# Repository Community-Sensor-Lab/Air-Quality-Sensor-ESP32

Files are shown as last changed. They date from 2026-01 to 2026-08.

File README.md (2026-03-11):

<div align="center">

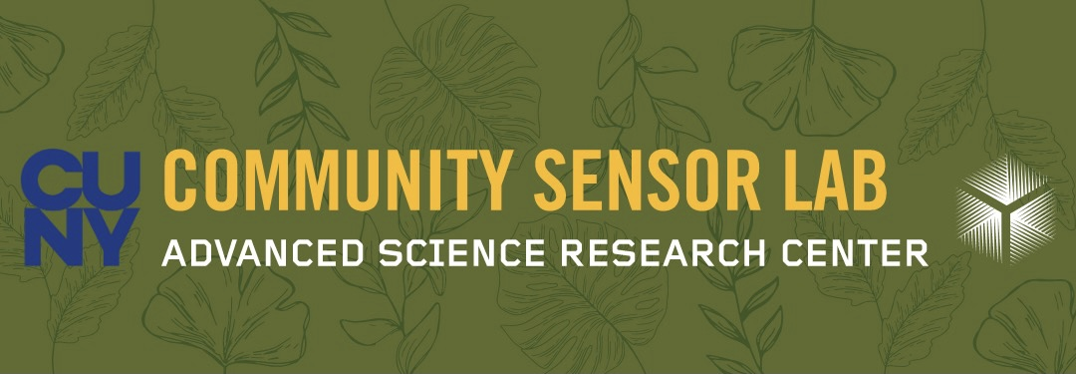
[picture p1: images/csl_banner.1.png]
Banner


</div>

#  Air Quality Sensor Assembly Guide (ESP32 version)

<div align="center">









*Build your own portable environmental monitoring station*

</div>

---

##  What You'll Build

<p align="center">
  
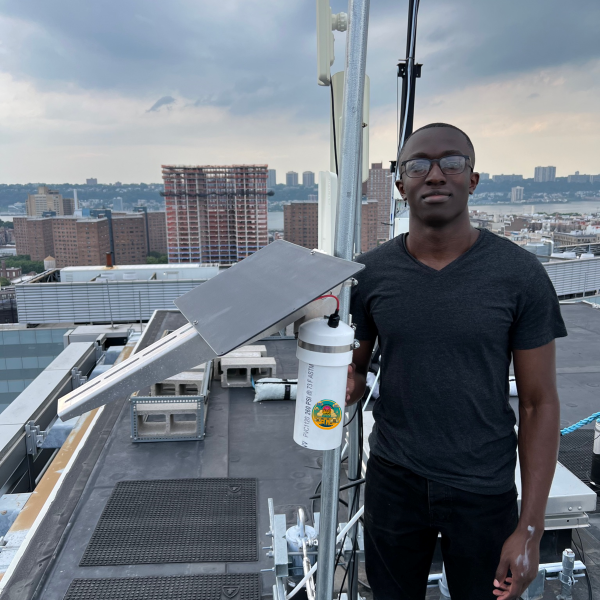
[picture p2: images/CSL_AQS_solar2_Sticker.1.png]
  
</p>

> **A complete air quality monitoring system** that measures Temperature, Relative Humidity, CO<sub>2</sub>, Volatiles (VOCs), Nitrogen Oxides (NOx), and particulate matter PM.

###  Key Features
-  **Multi-sensor monitoring** 5 environmental parameters
-  **SD card data logging** for long data records  
-  **Mini OLED screen** for real-time data display
-  **WiFi connectivity** integrated to Google Sheets
-  **Semi Portable design** for indoor/outdoor use

###  Learning Outcomes
By completing this project, you'll gain hands-on experience with:
-  **Electronics assembly** and soldering techniques
-  **Arduino programming** and sensor integration
-  **Data visualization** and analysis methods
-  **IoT connectivity** and cloud services

---

##  Project Overview

| **Duration** | **Difficulty** | **Prerequisites** |
|:---:|:---:|:---:|
| 6-8 hours | Beginner | Basic computer skills |

*Multiple sessions recommended for best learning experience*

---

##  Complete Guide Contents

| Section | Title | Author | Description |
|:---:|---|---|---|
| **0** | [ Parts List](Contents/Parts-List.md) | *Mark* | Complete components inventory |
| **1** | [ Skills & Tools](Contents/1.%20Required-Skills-and-Tools.md) | *Lorena* | What you'll need to get started |
| **2** | [ Arduino Setup](Contents/2.%20Installing-Arduino-and-Getting-Started-2.3.6.md) | *Vincent* | Software installation & basics |
| **3** | [ Soldering Guide](Contents/3.%20Soldering-Pins-and-Headers-on-Boards.md) | | Hardware assembly techniques |
| **3.5** | [ WiFi Configuration](Contents/3.5%20Feather-M0-WiFi-Setup-Procedure.md) | | Network connectivity setup |
| **4** | [ Component Assembly](Contents/4%20Breadboard-Assembly-and-Component-Code-Testing.md) | *Lorena* | Breadboard wiring & testing |
| **5** | [ Code Workshop](Contents/5.%20Code-Activity.md) | *Lorena* | Programming fundamentals |
| **6** | [ GitHub Integration](Contents/6.%20Downloading-CSL-AQS-Code-from-GitHub.md) | *Mark* | Source code management |
| **7** | [ Google Sheets Logging](Contents/7.%20Posting-to-Google-Logging-Spreadsheet.md) | *Vincent* | Cloud data integration |
| **8** | [ Data Visualization](Contents/8.%20How-to-Make-Data-Graphs-Lines-and-Time-Series.md) | *Ricardo* | Creating meaningful charts |
| **9** | [ PCB Design](Contents/9.%20Design-and-Assembly-of-PCB.md) | *Mark* | Professional circuit boards |
| **9.8** | [ Assembly of AQS Monitor on PCB Board](Contents/9.8%20Assembley-of-AQS-Monitor-on-PCB-Board.md) | | Soldering and mounting components onto the PCB |
| **10** | [ Final Assembly](Contents/10.%20AQS-PCB-Mount.md) | *Vincent* | Enclosure & mounting |

---

##  Quick Start

1. **Gather Materials** → Check the [Parts List](Contents/Parts-List.md)
2. **Setup Workspace** → Review [Skills & Tools](Contents/1.%20Required-Skills-and-Tools.md)
3. **Install Software** → Follow [Arduino Setup](Contents/2.%20Installing-Arduino-and-Getting-Started-2.3.6.md)
4. **Start Building!** → Begin with component assembly

---

##  Documentation Levels

| Guide Type | Best For | Link |
|---|---|---|
| **Quick Reference** | Experienced builders | *This README* |
| **Detailed Walkthrough** | First-time builders | [Comprehensive Guide](README-DETAILED.md) |

---

##  Perfect For

-  **STEM Education Programs**
-  **Students learning electronics**
-  **DIY environmental monitoring**
-  **Citizen science projects**

---

##  Contributing

Found an issue or have suggestions? We welcome contributions to improve this educational resource!

---

<div align="center">

**Transform your understanding of environmental monitoring while building something truly useful**





</div>

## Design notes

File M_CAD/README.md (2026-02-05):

<div align="center">

# Air Quality Sensor CAD

<div align="center">

### Most up-to-date CAD files for the Air Quality Sensor, including all mounts, stands and soldering tools.
---
<div align="center">

Complete Assembly of AQS with all Sensors
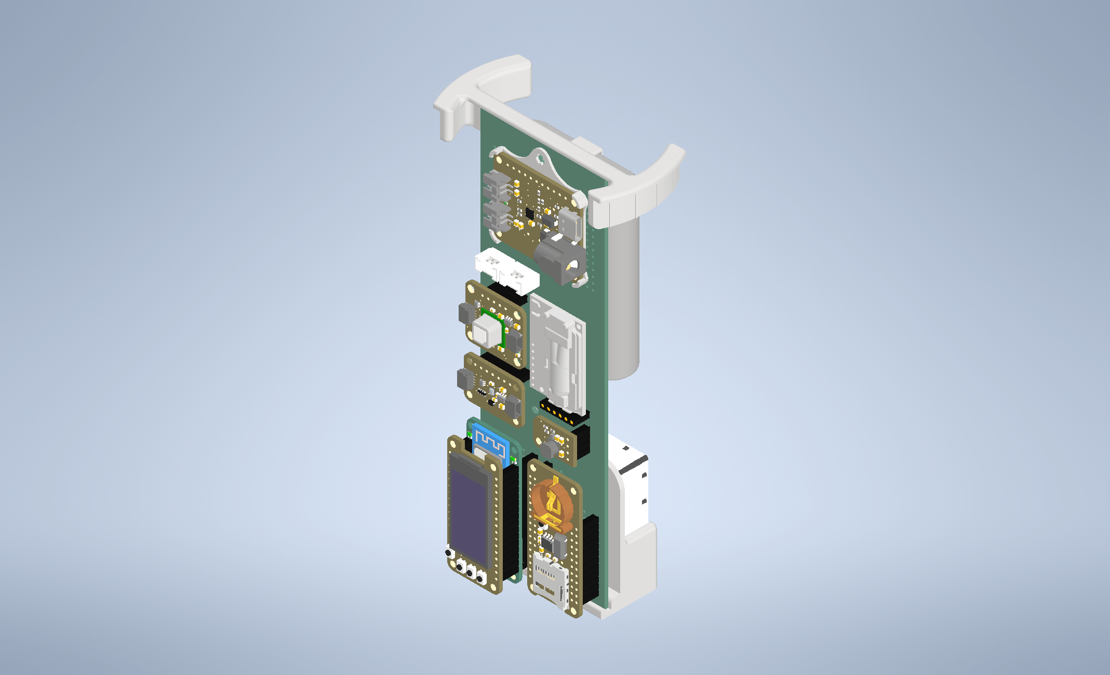
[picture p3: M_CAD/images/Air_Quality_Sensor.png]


Complete Assembly of Mounts Only
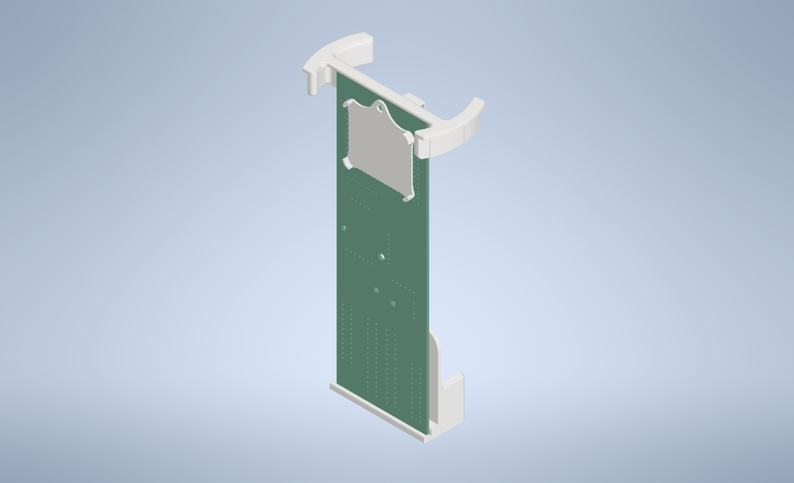
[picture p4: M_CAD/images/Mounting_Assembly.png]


</div>

---

>**All Mounts are Modeled using Inventor 2025**  
[Step Files included for Mounts Only]

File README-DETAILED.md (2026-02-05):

<div align="center">

Banner

</div>

#  Air Quality Sensor Assembly Guide
##  Detailed Step-by-Step Version

<div align="center">









*Complete educational walkthrough for building your environmental monitoring station*

</div>

---

##  About This Guide

This comprehensive guide provides **detailed, step-by-step instructions** for building an air quality monitoring system using Arduino-compatible components. Perfect for **classroom environments** and **self-paced learning**.

###  What You'll Build

<p align="center">
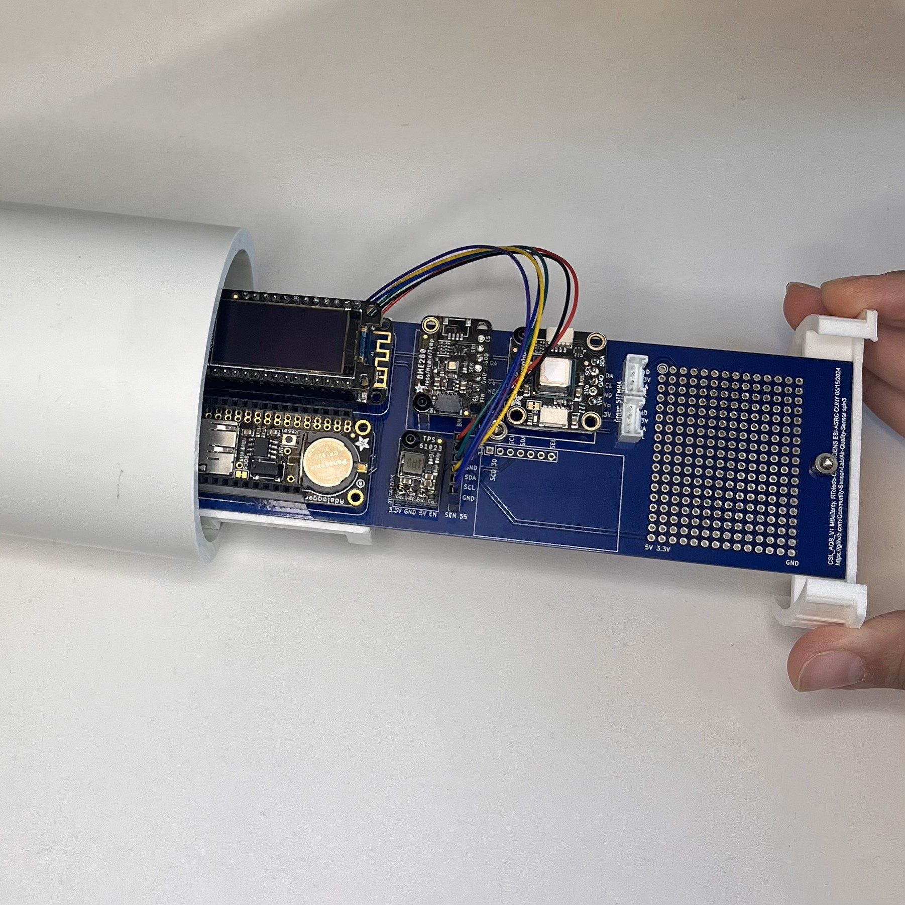
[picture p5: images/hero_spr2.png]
  
  
</p>

> **A complete air quality monitoring system** that measures temperature, humidity, CO2, VOC/NOX, and particulate matter—with data logging, real-time display, and cloud connectivity.

###  Project Specifications

| **Sensors** | **Data Storage** | **Connectivity** | **Display** |
|:---:|:---:|:---:|:---:|
| 5 Environmental | SD Card Logging | WiFi + Google Sheets | OLED Real-time |
| CO₂, VOC, PM2.5 | RTC Timestamps | Hotspot Provisioning | Serial Monitor |
| Temperature/Humidity | Offline Capable | Network Diagnostics | Status LEDs |

###  Educational Outcomes
By completing this detailed guide, students will master:
- **Hardware Skills**: Soldering, breadboarding, component assembly
- **Software Skills**: Arduino programming, library management, debugging
- **IoT Integration**: WiFi setup, cloud services, data visualization
- **Data Science**: Time series analysis, environmental monitoring concepts
- **Engineering Process**: Testing, troubleshooting, documentation

---

##  Quick Navigation

| **For Quick Start** | **For Deep Learning** |
|:---:|:---:|
|  [Streamlined Guide](Readme.md) |  *This Detailed Guide* |
| Perfect for experienced builders | Complete educational walkthrough |

---

##  Comprehensive Guide Contents

###  **Phase 1: Preparation & Setup**

| Section | Title | Author | Skills Developed | Duration |
|:---:|---|---|---|:---:|
| **0** | [ **Parts Inventory**](Contents/Parts-List.md) | *Mark* | Component identification, organization | 30 min |
| **1** | [ **Skills & Safety**](Contents/1.%20Required-Skills-and-Tools.md) | *Lorena* | Soldering, safety, tool usage, multimeter testing | 1 hour |
| **2** | [ **Arduino IDE Setup**](Contents/2.%20Installing-Arduino-and-Getting-Started-2.3.6.md) | *Vincent* | Software installation, board connection, basic programming | 45 min |

###  **Phase 2: Hardware Assembly**

| Section | Title | Author | Skills Developed | Duration |
|:---:|---|---|---|:---:|
| **3** | [ **Soldering Workshop**](Contents/3.%20Soldering-Pins-and-Headers-on-Boards.md) | | Advanced soldering, header installation, cable modification | 2 hours |
| **3.5** | [ **WiFi Provisioning**](Contents/3.5%20Feather-M0-WiFi-Setup-Procedure.md) | | Network configuration, wireless setup | 30 min |
| **4** | [ **Breadboard Assembly**](Contents/4%20Breadboard-Assembly-and-Component-Code-Testing.md) | *Lorena* | Circuit building, sensor integration, testing procedures | 1.5 hours |

**Key Learning Points:**
- **Soldering Mastery**: Header pins, stacking headers, JST connector rewiring
- **Component Integration**: BME280 → SCD41 → SEN5x sensor chain
- **Power Management**: RTC battery installation, SD card formatting
- **Testing Protocols**: Serial monitor diagnostics, OLED status display

###  **Phase 3: Programming & Integration**

| Section | Title | Author | Skills Developed | Duration |
|:---:|---|---|---|:---:|
| **5** | [ **Code Integration**](Contents/5.%20Code-Activity.md) | *Lorena* | Code merging, programming logic, debugging | 45 min |
| **6** | [ **Firmware Deployment**](Contents/6.%20Downloading-CSL-AQS-Code-from-GitHub.md) | *Mark* | GitHub workflows, firmware flashing, troubleshooting | 30 min |

**Technical Focus:**
- **Code Architecture**: Understanding sensor libraries and data flow
- **Debugging Skills**: Serial output analysis, OLED diagnostics
- **Version Control**: GitHub integration, firmware management

###  **Phase 4: Data & Connectivity**

| Section | Title | Author | Skills Developed | Duration |
|:---:|---|---|---|:---:|
| **7** | [ **Cloud Integration**](Contents/7.%20Posting-to-Google-Logging-Spreadsheet.md) | *Vincent* | API integration, cloud services, data streaming | 45 min |
| **8** | [ **Data Visualization**](Contents/8.%20How-to-Make-Data-Graphs-Lines-and-Time-Series.md) | *Ricardo* | Time series analysis, graph creation, trend analysis | 1 hour |

**Data Science Skills:**
- **Cloud APIs**: Google Sheets integration, automated logging
- **Visualization**: Time series plots, environmental trend analysis
- **Analysis**: Pattern recognition in air quality data

###  **Phase 5: Professional Assembly**

| Section | Title | Author | Skills Developed | Duration |
|:---:|---|---|---|:---:|
| **9** | [ **PCB Design**](Contents/9.%20Design-and-Assembly-of-PCB.md) | *Mark* | PCB layout, professional assembly, manufacturing | 1 hour |
| **9.8** | [ **Assembly of AQS Monitor on PCB Board**](Contents/9.8%20Assembley-of-AQS-Monitor-on-PCB-Board.md) | | Soldering components, wiring sensors, PCB mounting | 50 min |
| **10** | [ **Enclosure Design**](Contents/10.%20AQS-PCB-Mount.md) | *Vincent* | 3D printing, mechanical design, product finishing | 45 min |

**Engineering Skills:**
- **PCB Development**: Design files, ordering process, assembly techniques
- **Mechanical Design**: 3D printed mounts, PVC enclosures
- **Product Integration**: Professional finish, deployment readiness

---

##  Learning Path Recommendations

###  **For Individual Learners**
1. **Start with Phase 1** → Build foundational skills
2. **Take breaks between phases** → Allow time for concept absorption
3. **Document your progress** → Keep a build journal
4. **Test thoroughly at each step** → Catch issues early

###  **For Classroom Use**
- **Session 1**: Parts inventory + Skills training (Sections 0-1)
- **Session 2**: Arduino setup + Soldering workshop (Sections 2-3)
- **Session 3**: Assembly + Testing (Section 4)
- **Session 4**: Programming + Cloud setup (Sections 5-7)
- **Session 5**: Data analysis + PCB assembly (Sections 8-10)

###  **For Experienced Builders**
- Use the [ Streamlined Guide](Readme.md) for faster assembly
- Reference this guide for detailed troubleshooting
- Focus on Phases 4-5 for advanced features

---

##  Important Prerequisites

###  **Knowledge Requirements**
-  Basic computer literacy
-  Willingness to learn electronics
-  Patience for step-by-step assembly
-  Basic understanding of environmental science (helpful)

###  **Required Equipment**
-  Soldering iron and supplies
-  Computer with USB port
-  Internet connection for downloads
-  Workspace with good lighting

---

##  Getting Help

###  **Support Resources**
- **Issues & Bugs**: Use GitHub Issues for technical problems
- **Discussion**: GitHub Discussions for general questions
- **Documentation**: Refer to individual section guides
- **Troubleshooting**: Each section includes diagnostic steps

###  **Success Indicators**
- [ ] All sensors reading valid data
- [ ] SD card logging timestamps
- [ ] OLED display showing current readings
- [ ] WiFi connected and uploading to Google Sheets
- [ ] Clean, professional assembly

---

##  Project Completion

Upon finishing this guide, you'll have:
- **A fully functional air quality monitoring station**
- **Real-time environmental data collection**
- **Cloud-connected data logging system**
- **Comprehensive electronics and programming skills**
- **Ability to analyze environmental trends**

---

<div align="center">

**Ready to get started? Follow the detailed sections above for complete assembly instructions.**





</div>

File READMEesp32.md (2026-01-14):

# CSL_AQS_ESP32_V1
CSL code for the AQS system running with an **Adafruit Feather ESP32 V2** (faster, cheaper, better).
- Includes [Fahmin Rahman](https://youtu.be/Kc8zY-2nlwo?si=XONh5ZNkazO3LDjU) contributions (improved provisioning, extended information output) merged to main.
- tbd finish Jonathan Suconota's get routines

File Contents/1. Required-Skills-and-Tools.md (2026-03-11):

# Electronics Skills Guide

## Soldering Safety

**Always follow these safety guidelines before beginning any soldering work:**

* Wear eye protection (goggles or safety glasses)
* Never touch a hot soldering iron to yourself or anyone else
* When not using the soldering iron, place it in a soldering iron holder to avoid fires and burn accidents
* Lower the power or turn off the soldering iron when it is not in use
* Do not directly expose yourself or others to solder fumes. Ensure proper ventilation with an air current (fan, etc.) or fume extractor for the solder smoke

## Soldering Practice

### Materials Needed
* Solder training boards (protoboards)
* Solder training pins
* Breadboard

### Tools Required
* Soldering station with cleaning sponge, metal wool and iron holder
* Solder wire
* Fan or exhaust for ventilation
* Magnifier
* Good lighting
* Soldering tip tinner/cleaner

### Basic Soldering Procedure (For Beginners)

1. **Setup**: Put two rows of male header pins into the breadboard with the long pins down and place the training board on top with the text facing up so that the short pins poke out of the training board where you want them.

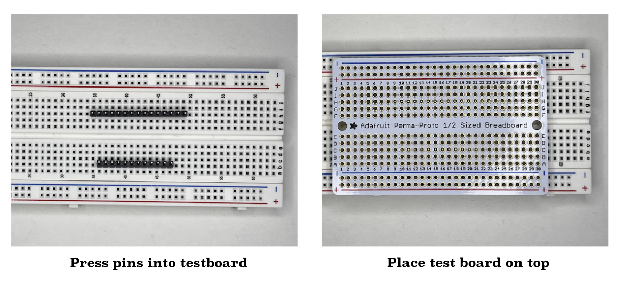
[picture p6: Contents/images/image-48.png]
   

2. **Prepare the iron**: Turn on the soldering iron and set the temperature to the suggested value (about 300-350 C). Wait until it reaches the set temperature.

3. **Begin soldering**: Starting on one end of the row of pins, place the flat end of the tip of the soldering iron on the pin and pad so that it touches them both simultaneously, then bring the solder wire to the junction.

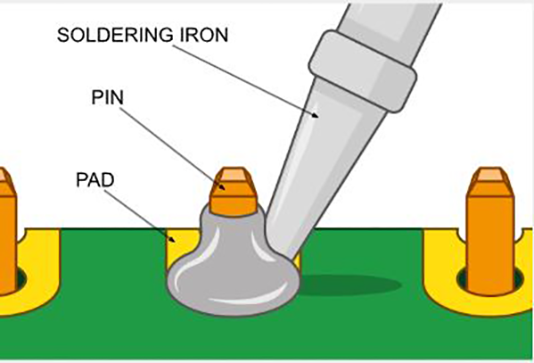
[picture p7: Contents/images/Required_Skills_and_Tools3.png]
   

4. **Apply solder**: Melt a small bead of solder and hold the hot iron until the solder is 'sucked' into the pad.

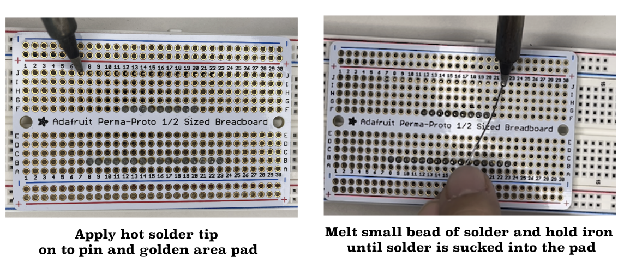
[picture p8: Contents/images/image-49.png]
   

5. **Remove iron**: Quickly remove the iron (be aware of time, since the board can get overheated).

6. **Continue**: Repeat with the pin on the opposite end and continue going back and forth until you finish the last pin somewhere in the middle. This allows the area around the soldered pins to cool off a little.

7. **Practice**: Practice this technique for several rows of pins.

The objective is to heat the pin, pad and solder so that it becomes 'wet' and is sucked into the pad and leaves behind a uniform cone-shaped amount holding the pin and the pad together. Too much solder can short adjacent pins and is hard to inspect.

### Advanced Soldering: Without Breadboard Support

The challenge of soldering pins to boards without support is to get the pins straight and flush with the board. To do this, solder only one pin and then inspect for straightness. If it's crooked in any way, you can reapply heat to the one pin and reseat the pins until they are straight. Do this before continuing because if you solder more than one pin melting them two pins simultaneously is difficult.

**When you're ready to solder directly to PCB boards:**

1. **Position components**: As best you can, place the pins or header into the PCB board and place the board on the table with the longer end of the pins/header sitting at an angle to the table.

2. **First solder joint**: Apply the soldering iron to an end pad and pin, allowing the iron to heat the pad/pin.

3. **Add solder**: Place the soldering wire into the iron/pad/pin junction.

4. **Create joint**: Melt a small bead of solder into the pad and hold until the melted solder is 'sucked' into the pad/pin.

5. **Remove iron**: Quickly remove the iron. At this point the pins will probably be crooked with respect to the PCB board.

6. **Align header**: With one hand, hold the PCB board and place a finger on the header on the opposite side and end of the newly soldered pin.

7. **Re-melt and align**: Apply the iron onto the soldered pin to re-melt the solder. This will allow you to align the header with your finger to make a 90-degree angle with the test board.

8. **Continue soldering**: This single soldered pin will hold the entire row of pins or header in position, allowing you to proceed as above with the rest of the pins! 

   **Note**: Make sure to apply enough pressure so the header makes full contact with the PCB board.

**Video demonstration**: [Edited Video of Advanced Soldering.mp4](https://drive.google.com/file/d/1IDuTgYlEillcRoKbDvMZIReiyKo5U2Oj/view?usp=sharing)

### Additional Soldering Resources from the Internet
* [How to Solder Pin Headers](https://www.youtube.com/watch?reload=9&app=desktop&v=TFfMYYBRu30)
* [Collin's Lab: Soldering](https://www.youtube.com/watch?v=QKbJxytERvg)
* [From Solderless Breadboard to Soldered Circuit - Electronics with Becky Stern | Digi-Key Electronics](https://www.youtube.com/watch?v=F9Krq7seV1g)
* [Let's Play - Toobers!](https://web.mit.edu/2.00b/www/toobers/pcbassembly1.html)

## Wire Preparation: Stripping Solid Jumper Wires

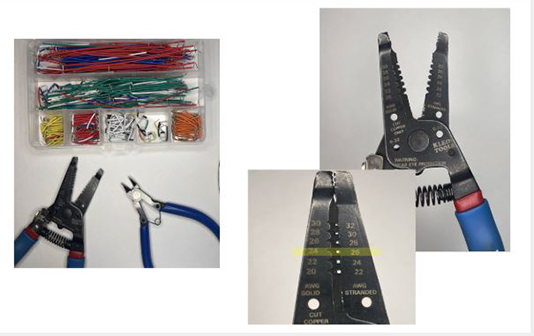
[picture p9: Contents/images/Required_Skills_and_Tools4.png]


### Materials and Tools
* Solid jumper wires
* Wire snips
* Wire stripper

### Procedure
1. **Measure length**: First, estimate how long you will need the cable to be by laying it down to the points you are trying to connect and leaving room for the insertion part.

2. **Cut to length**: Next, grab the snips and cut the desired length.

3. **Strip ends**: Once you have the length you want, grab the wire stripper and strip off the ends that will be inserted into the breadboard.

### Video Tutorial
* [Cutting Perfect Jumper Wires](https://www.youtube.com/watch?v=ver-Av8vr1Q)

## Testing Connections: Using the Multimeter

### Tools Required
* Multimeter
* Testing leads (banana plugs/alligator clips/test hooks)
* Assembled and wired board (i.e., any connection you'd like to test)

### Testing Procedure

1. **Setup multimeter**: Grab a multimeter and connect leads to respective inputs.

2. **Select function**: Turn on the multimeter to the desired test function. For this procedure we will be using the continuity function (wave of curved lines).

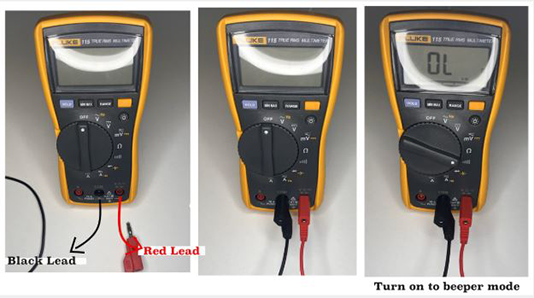
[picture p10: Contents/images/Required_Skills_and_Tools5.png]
   

3. **Test multimeter**: Once the multimeter is set to the continuity function, touch the two leads together. If you hear a beeping noise, the continuity function is working properly.

4. **Test connection**: Touch the probes to each end of the connection you want to test. If you hear a beep, the connection is stable.

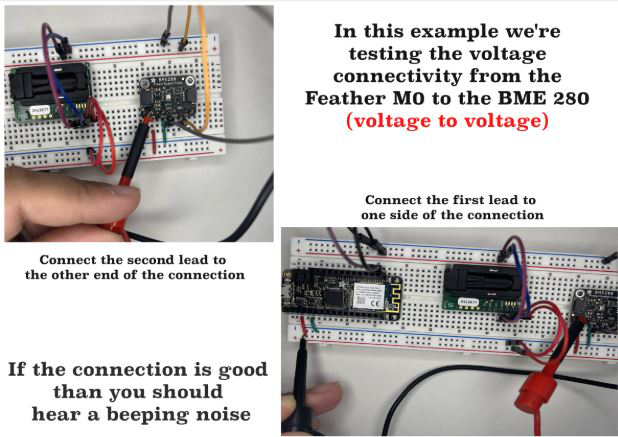
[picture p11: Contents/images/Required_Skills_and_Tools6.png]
   

## Additional Learning Resources from the Internet

* [How to Solder Pin Headers](https://www.youtube.com/watch?reload=9&app=desktop&v=TFfMYYBRu30)
* [Collin's Lab: Soldering](https://www.youtube.com/watch?v=QKbJxytERvg)
* [From Solderless Breadboard to Soldered Circuit | Digi-Key Electronics](https://www.youtube.com/watch?v=F9Krq7seV1g)
* [Let's Play - Toobers!](https://web.mit.edu/2.00b/www/toobers/pcbassembly1.html)

### Wire Preparation Tutorial
* [Cutting Perfect Jumper Wires](https://www.youtube.com/watch?v=ver-Av8vr1Q)

### Multimeter Tutorial
* [What is Continuity and How to Test](https://www.youtube.com/watch?v=5G622WDZaHg)

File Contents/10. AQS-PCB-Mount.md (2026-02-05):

# 3D Printing and Assembly Guide

## Finding Files
Files for both the PCB and Sensirion Mount will be located on the [Community Sensor Github](https://github.com/Community-Sensor-Lab/Air-Quality-Sensor/tree/master)

- Download and import the STL files into your 3D Printing Software
- Add supports wherever required

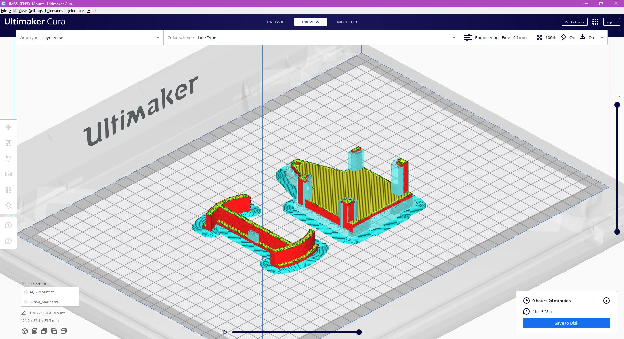
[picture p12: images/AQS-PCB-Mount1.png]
PCB Mount Overview


---

## Assembly Instructions

### Step 1: Thread Preparation
When the two mounts are completed, thread the holes with a 6-32 thread (Not required on newest mount iterations)

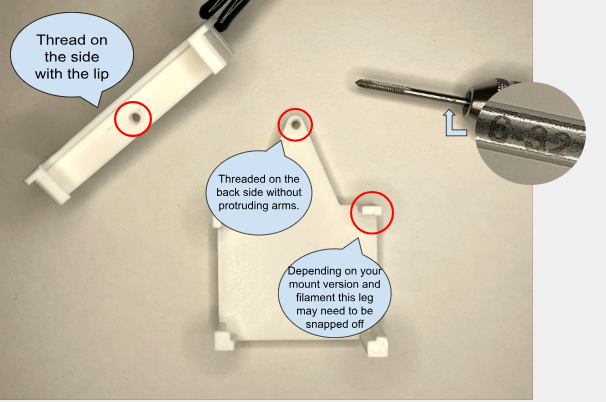
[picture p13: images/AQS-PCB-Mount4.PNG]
Threading the Mount


### Step 2: PCB Mount Installation
Secure the AQS Mount onto the top hole with a [Grainger #6 Screw](https://www.grainger.com/) (6-32 x 12" Phillips Head Screw) with a 6-32 lock nut and a Phillips Bit or 6-32 x 12" Screw with a 6-32 lock nut and a [H2.5 Bit](https://www.mcmaster.com/). 

**Important:** Make sure that the PCB is screwed into the side with the Lip so that the PCB will be secure in a vertical position.

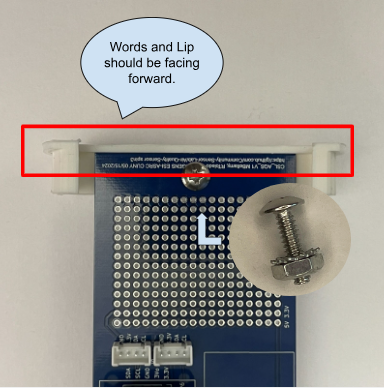
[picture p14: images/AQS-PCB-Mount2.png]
PCB Mount Installation


### Step 3: Sensor Installation
Insert the [SEN5X](https://sensirion.com/products/catalog/SEN54/) into the Mount

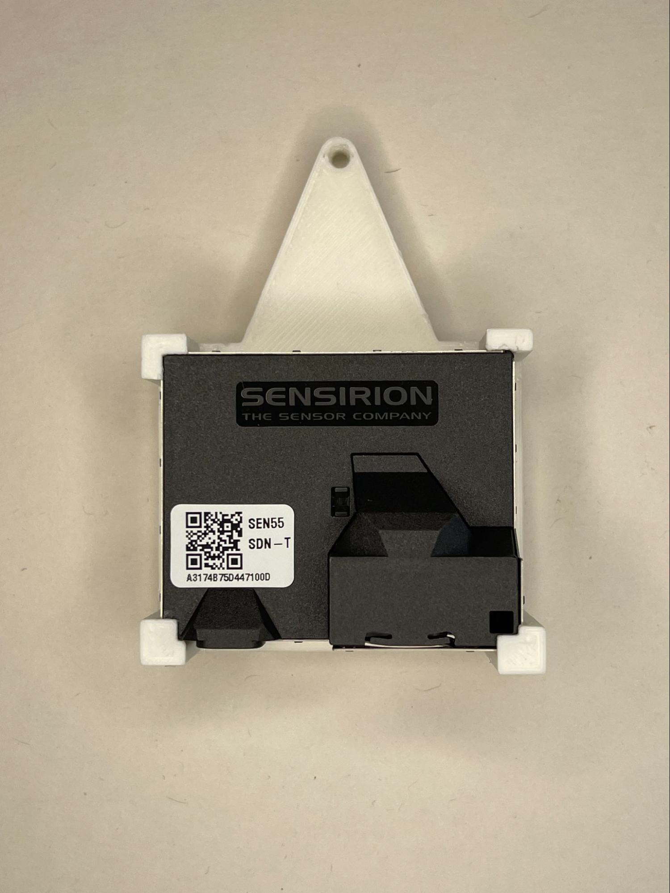
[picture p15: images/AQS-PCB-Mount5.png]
Sensor Installation


### Step 4: Alignment Check
Make sure that the holes line up for the SEN5X Mount and the PCB Board

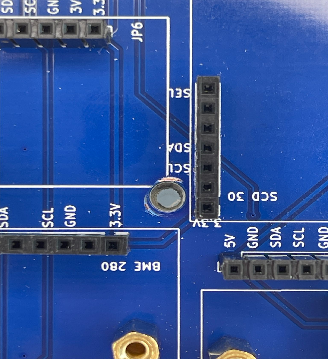
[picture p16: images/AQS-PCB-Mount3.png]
Alignment Check


### Step 5: Sensor Mount Security
Secure the SEN5X Mount using the hole in the middle of the PCB. Use a 6-32 x 12" Screw with a 6-32 lock nut and a H2.5 Bit or 6-32 x 12" Phillips Head Screw. 

**Note:** This mount should be on the back of the PCB with all the soldered joints.

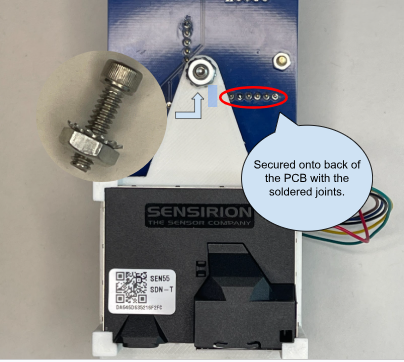
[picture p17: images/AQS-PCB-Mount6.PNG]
Sensor Mount Security


### Step 6: Final Assembly
Insert the AQS into a [3in PVC Pipe](https://www.homedepot.com/). It is a tight fit so try to use moderate pressure while rotating the AQS for it to be fully placed into the PVC Pipe.

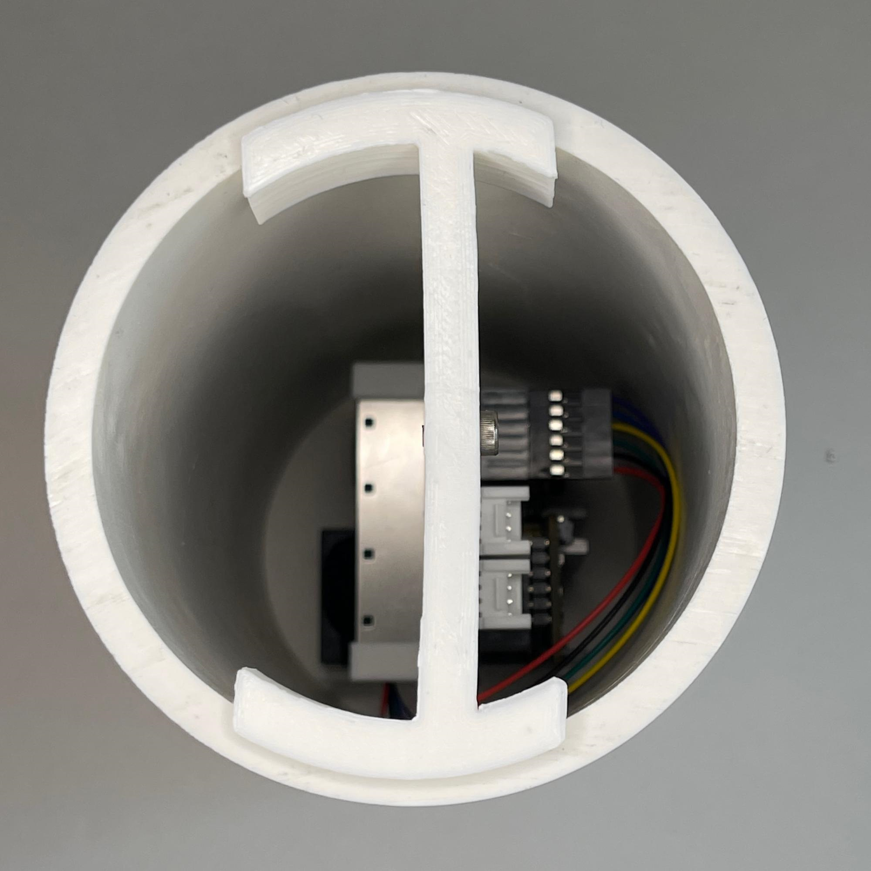
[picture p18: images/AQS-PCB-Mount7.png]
Final Assembly


---

## Required Materials
- 6-32 x 12" Phillips Head Screws
- 6-32 lock nuts
- Phillips screwdriver or H2.5 Bit
- 3" PVC Pipe
- SEN5X Sensor
- 3D printed PCB and Sensirion mounts

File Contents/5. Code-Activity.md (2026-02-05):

# Code Activity

In this section we're going to get an understanding on where the main code comes from by merging example codes. When merging example codes, we'll be able to test and run two sensors at once. For this exercise we'll be using the [SparkFun single shot code](https://github.com/sparkfun/SparkFun_SCD4x_Arduino_Library/tree/main/examples) and the [BME280 test code](https://github.com/adafruit/Adafruit_BME280_Library/tree/master/examples).

## Prerequisites

If you don't already have the library installed; be sure to install [SparkFun SCD4x Arduino Library](https://github.com/sparkfun/SparkFun_SCD4x_Arduino_Library) through the library manager. This is where you will be able to find the single shot example code.

## Initial Setup

### Opening Up Both Example Codes
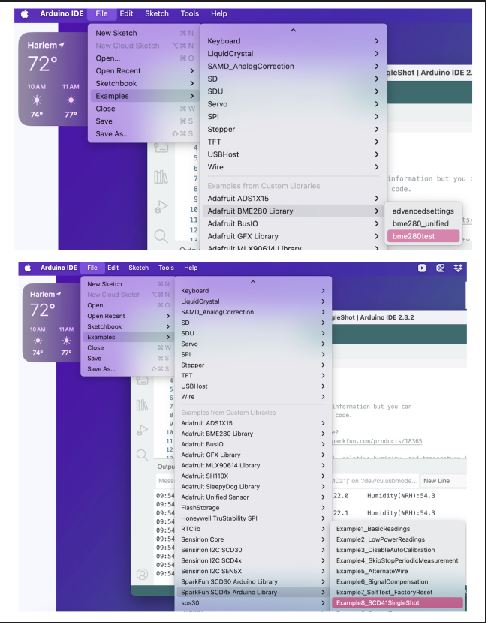
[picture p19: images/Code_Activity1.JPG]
Code Activity Setup


### SCD41SingleShot Edit

Before we continue we will have to make a slight modification to the code. Highlight lines 76 through 92 and click command forward slash (mac) or control forward slash (windows). This will comment out that section of the code, so that the section is disabled when uploading it. **Also change line 35 to false,false,false.**

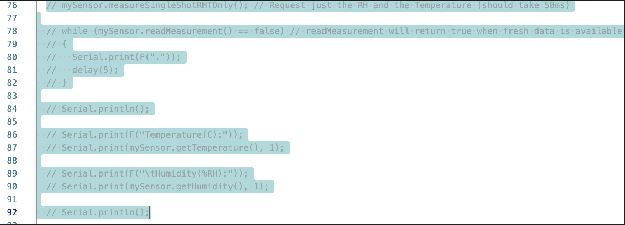
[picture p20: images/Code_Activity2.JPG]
Code Modification


Now we have everything ready to start merging the code.

## Procedure

### Step 1: Create and Set Up New Sketch

Let's start off by creating and setting up our new sketch.

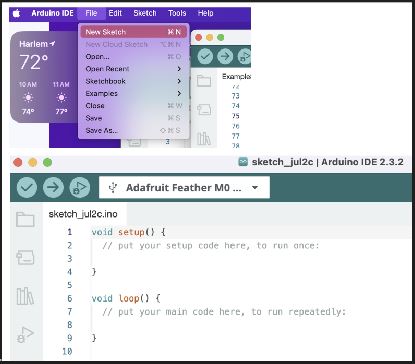
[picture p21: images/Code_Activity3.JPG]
New Sketch Creation


### Step 2: Create Function Tabs

In the sketch we will start off by creating tabs for our functions. We will have four tabs:
1. **SCD41_initial**
2. **BME280_initial** 
3. **SCD41_loop**
4. **BME280_loop**

Creating these functions will help us better manage our code.

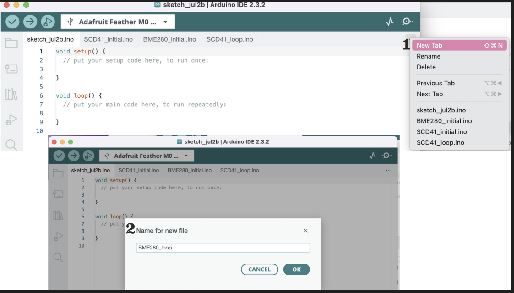
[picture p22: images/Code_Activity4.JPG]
Function Tabs


### Step 3: Copy Initial Code Sections

Start by copying over the section before void setup() from both example codes and pasting it on to our new sketch before void setup().

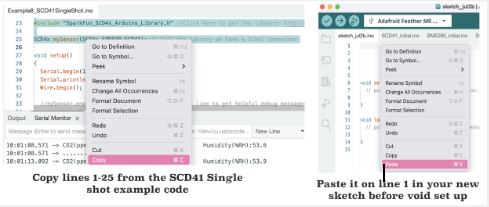
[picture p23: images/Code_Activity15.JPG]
Copy Initial Code 1


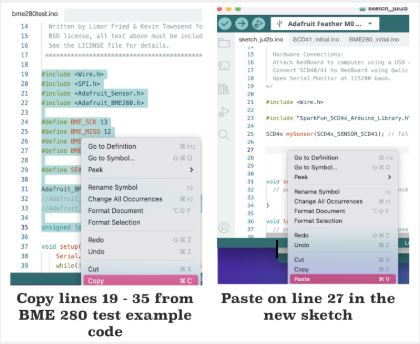
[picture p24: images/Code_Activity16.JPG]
Copy Initial Code 2


### Step 4: Populate Function Tabs

#### 4a. SCD41_initial Tab

For the SCD41_initial we will copy over the void setup() code:

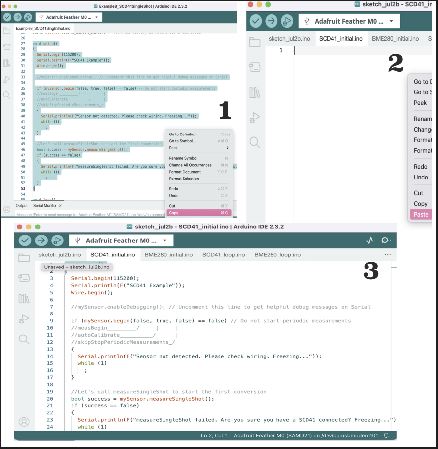
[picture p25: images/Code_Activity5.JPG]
SCD41 Setup Code


Next we will give the function a new name by replacing setup() with SCD41_initial (recommended) or choose your own name.

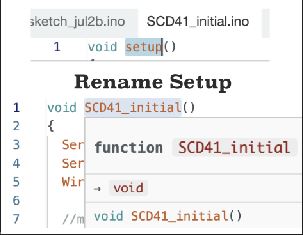
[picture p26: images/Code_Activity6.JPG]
SCD41 Function Rename


Choose a good name as it will stick and you want to be able to easily identify the function.

#### 4b. BME280_initial Tab

Repeat the same steps for the BME280_initial tab:
1. Copy the void setup code
2. Paste it into the tab

BME280 Initial Setup

Add `delay(delayTime);` into the end of the function as shown above.

Remove printValues() in line 70 under void loop();

Copy and Paste lines 76 to line 93 into Void loop. This function should be put under the tab BME280_loop.

BME280 Loop Function

Rename the function appropriately.

#### 4c. SCD41_loop Tab

For the SCD41 loop we will be copying over the void loop code into the tab and renaming the function as well.

SCD41 Loop Code

#### 4d. BME280_loop Tab

Repeat the same process for copying over the BME280 loop into the BME280_loop tab:
1. Copy over the void printValues
2. Add `delay(delayTime);` under the Serial.println();

BME280 Loop Complete

### Step 5: Add Functions to Main Tab

Now we will add the functions we have created to the first tab like so:

Function Integration

### Step 6: Code Completion

Our code is now complete!

### Step 7: Verify and Upload

Next step is to verify and upload the code to our sensors:

Code Verification

Code Upload

### Step 8: Monitor Results

Once the upload is complete press the serial monitor at the top right corner to see your data results.

Serial Monitor Results

---

## Additional Resources

- [Arduino IDE Documentation](https://docs.arduino.cc/software/ide-v2/)
- [SparkFun SCD4x Library Documentation](https://github.com/sparkfun/SparkFun_SCD4x_Arduino_Library)
- [BME280 Sensor Information](https://www.bosch-sensortec.com/products/environmental-sensors/humidity-sensors-bme280/)
- [Serial Monitor Guide](https://docs.arduino.cc/software/ide-v2/tutorials/ide-v2-serial-monitor/)

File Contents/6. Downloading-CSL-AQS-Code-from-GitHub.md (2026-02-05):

# Community Sensor Lab Air Quality Sensor Setup Guide

## Overview
The Community Sensor Lab's DIY Air Monitoring files include instructions on assembling and operating the air quality monitor. This guide will walk you through downloading the code, setting up your development environment, and configuring your sensor.

## Prerequisites
- Computer with internet access
- Air Quality Sensor hardware (Adafruit Feather M0)
- USB cable for connecting the sensor
- WiFi network credentials

---

## Step 1: Understanding GitHub and Accessing Our Code

[GitHub](https://github.com/) is an online platform where code is stored, shared, and collaboratively worked on. You **don't** need a GitHub account to visit the site or download the code.

### Accessing the Community Sensor Lab Repository

1. Visit: [Community Sensor Lab](https://github.com/Community-Sensor-Lab)
2. Go to the **Repositories** drop-down menu
3. Find and click on **Air-Quality-Sensor**

---

## Step 2: Exploring the Air Quality Sensor Repository

Once the [Air Quality Sensor Repository](https://github.com/Community-Sensor-Lab/Air-Quality-Sensor) opens, you'll see several important folders:

- **[CSL-AQS-V2.1](https://github.com/Community-Sensor-Lab/Air-Quality-Sensor/tree/master/CSL-AQS-V4)**: Contains all the code you need to run your Air Quality Sensor
- **[Images](https://github.com/Community-Sensor-Lab/Air-Quality-Sensor/tree/master/images)**: Contains all the images referenced in the [README.md file](https://github.com/Community-Sensor-Lab/Air-Quality-Sensor/blob/master/README.md), including instructions and additional information about AQS
- **[wifi_logger_proto.gs](https://github.com/Community-Sensor-Lab/Air-Quality-Sensor/blob/master/wifi_logger_proto.gs)**: Contains code for connecting the sensor to Google Sheets

---

## Step 3: Downloading the Code

1. Look for the green **Code** button  on the repository page
2. Click on it to reveal the dropdown menu
3. Under **HTTPS**, select **Download ZIP**



4. Click **Download ZIP** to start the download
5. Once the download is complete, locate the **Air-Quality-Sensor-master.zip** file
6. Extract the zip file:
   - **Windows**: Right-click the zip file and select "Extract All"
   - **macOS**: Double-click the zip file
   - **Linux**: Use your file manager or command line to extract
7. Save the extracted **Air-Quality-Sensor-master** folder in a location where you can easily find it again
8. **Important**: You will only need the **CSL-AQS-V2.1** folder for the main code
9. You can delete the zip file after extraction, but keep the images, README.md, and wifi_logger_proto.gs files for reference

---

## Step 4: Installing Arduino IDE

Before you can upload code to your sensor, you need to install the Arduino development environment.

### Installation Steps:

1. Visit the Arduino website: [https://www.arduino.cc/en/software](https://www.arduino.cc/en/software)
2. Scroll down and select the download version compatible with your operating system:
   - **Windows**: Windows Win 10 and newer
   - **macOS**: macOS Monterey or newer
   - **Linux**: Linux 64-bit
3. Follow the installation prompts based on your system
4. Once installed, open the Arduino IDE to confirm it's working correctly

### Installing Required Board Support:
1. Open Arduino IDE
2. Go to **Tools** > **Board** > **Boards Manager**
3. Search for "Adafruit SAMD" and install the **Adafruit SAMD Boards** package

---

## Step 5: Loading and Configuring the Code

### Opening the Code in Arduino IDE

Arduino IDE File Menu

1. In Arduino IDE, select **File** → **Open**
2. Navigate to your downloaded **CSL-AQS-V2.1** folder
3. Select the main `.ino` file to open the project

### Configuring Board Settings

Before **compiling** and **uploading** the code, you must configure the correct board and port settings.

#### Setting the Board:
Board Selection

1. Select **Tools** > **Board** > **Adafruit SAMD Boards** > **Adafruit Feather M0**
2. Verify the board name reads "Adafruit Feather M0 (SAMD21)"

#### Setting the Port:
Port Selection

1. Connect your Adafruit Feather M0 to your computer via USB
2. Select **Tools** > **Port** > **[Sensor Name]** (e.g., Adafruit Feather M0)
3. The port should match the Adafruit Feather M0 name (SAMD21)

### Compiling and Uploading the Code

Arduino IDE Toolbar

After reviewing the code, use the two buttons on the left side of the **Tool Bar**:

1. **Checkmark (✔)**: Click to **compile** the sketch and check for errors
2. **Right Arrow (➔)**: Click to **upload** the code to your sensor

**Note**: Always compile first to check for errors before uploading.

---

## Step 6: WiFi and Google Sheets Configuration

This step connects your sensor to your WiFi network and enables data logging to Google Sheets.

### WiFi Provisioning Process

The sensor needs to be provisioned (set up) to connect to your WiFi network. **Important**: The sensor must connect to a standard WiFi network (not enterprise networks with special authentication).

#### Provisioning Steps:

1. **Power on your sensor** - The OLED screen will display the sensor's temporary WiFi network name
2. **Connect your phone or computer** to the AQS system's WiFi network (shown on the OLED screen)
3. **Open a web browser** and navigate to: [https://192.168.1.1/](https://192.168.1.1/)
4. **Enter your WiFi credentials**:
   - WiFi network name (SSID)
   - WiFi password
5. **Click 'Submit'** to save the configuration
6. **Wait for confirmation** - The sensor will restart and connect to your WiFi network

### Google Sheets Integration (Optional)

If you want to log data to Google Sheets, refer to the `wifi_logger_proto.gs` file in the repository for detailed setup instructions.

---

## Troubleshooting

### Common Issues:

- **Board not detected**: Ensure USB cable is properly connected and drivers are installed
- **Compilation errors**: Check that you have the correct board package installed
- **WiFi connection fails**: Verify network credentials and ensure you're using a standard WiFi network
- **Upload fails**: Press the "RESET" button on the board two times to get the Feather M0 board ready to receive code

### Getting Help:

Visit the [Community Sensor Lab GitHub repository](https://github.com/Community-Sensor-Lab/Air-Quality-Sensor) for additional resources and community support.

---

## Next Steps

Once your sensor is configured and connected:
1. Monitor air quality readings on the OLED display
2. Access logged data through your configured Google Sheets (if set up)
3. Consider joining the Community Sensor Lab community for tips and collaboration

**Happy monitoring!**

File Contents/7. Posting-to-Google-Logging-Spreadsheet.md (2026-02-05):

# Air Quality Monitor - Google Logging Spreadsheet Setup Guide

## Overview

With a connection to a WiFi network, you can upload the data from the Air Quality Monitor to a Google spreadsheet in real time. To accomplish this, you must sign in using a Google account.

We have created a spreadsheet template where the data will be automatically uploaded. The Air Quality Monitor can be programmed to send data via WiFi, Bluetooth, or serial communication to a Google Spreadsheet using a deployment protocol, as outlined in document number 6.

---

## Part I: Getting Started with the Spreadsheet

### Step I: Access the Spreadsheet Template
Click on the link to access the spreadsheet:
**[📊 CSL-AQS-Template](https://docs.google.com/spreadsheets/d/1c2Fz-3yoDlgtHRTSywHb1Qw0Rqlr5v1rYq2KaVxd2Ac/edit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)**

### Step II: Make a Copy
Once the spreadsheet opens, go to the **File → menu** and **Make a Copy** of the spreadsheet. It's important you make a copy because this is not a spreadsheet you can edit.

File Menu - Make a Copy

### Step III: Save and Name Your Copy
Save the copy in your own Google Drive to be able to edit it.

**Name the spreadsheet** to identify the location, project, owner, or any other label that will help identify the data for the specific air monitor. If you can find the GPS coordinates, you can add this to the spreadsheet's name.

### Step IV: Review the Data Structure
Notice the different titles with respective units of the spreadsheet columns. Once you have completed these steps, your spreadsheet will collect data in real time!

---

## Part II: Deploying Google Script for Remote Data Upload

### Understanding the Technology

**Tool:** [Google Apps Script](https://developers.google.com/apps-script) - a cloud-based scripting language integrated into Google Sheets

**Purpose:** The script will automate the process of updating the Google Sheet

**How It Works:** The script uses HTTP methods (GET, POST, PUT, DELETE) to send or retrieve data to and from Google Sheets

We will use App Script to update the Google Sheet via HTTP. Google Apps Script makes creating and publishing add-ons for Google Docs, Sheets, Slides, and Forms easy. To learn more, visit **[Automate & extend Google Workspace with Simple Code](https://developers.google.com/apps-script)**.

### Step I: Open the Script Editor
To open the Script Editor, go to the **Extensions** drop-down menu and select **Apps Script**.

Extensions Menu - Apps Script

This page will pop up:

Apps Script Editor Interface

The AQS (Air Quality Systems) Data Spreadsheet Logger will pop up. If you get an error message instead, see the [Troubleshooting section](#troubleshooting) below.

The AQS collects, records, and stores air quality data.

### Step II: Verify or Add Script Code
If you have followed these steps **with** the spreadsheet template we provided, you should see several lines of code when you open the script editor. The code will be needed for the following steps.

**If you did not use the template:**
1. You can find the code in our Air Quality Sensor repository: **[github.com/Community-Sensor-Lab/Air-Quality-Sensor](https://github.com/Community-Sensor-Lab/Air-Quality-Sensor)**
2. Locate the file: `WiFi_logger_proto.gs`
3. Copy the code in this file and paste it into the script editor

### Step III: Configure Your Spreadsheet ID

#### Modifying Spreadsheet Name and ID
2. **Line 55** is an important line that you need to edit (line number is different in image below)

Code Editor - Line 55

3. Line 55 says, `'enter id here.'` This line must be replaced with the **ID of your spreadsheet**. Every single Google Spreadsheet link has its unique ID

4. **To find the ID:** Return to your Google spreadsheet. The URL contains your spreadsheet ID

URL Structure Example

5. **Locate the ID:** The ID is located between the **d/** and the **/edit** of the URL. Copy this long string of characters and paste it between the quotation marks in the code, replacing the placeholder text: `"enter id here,"` as illustrated below:

Spreadsheet ID Location

6. **Test the Script:** Press **"RUN"**

---

## Part III: Deploying Your App Script

### Step IV: Deploy the Application

Now that your App Script is ready, you must deploy it. An App Script deployment is a version of the script made available for use as a web app, add-on, or API executable.

1. **Deploy:** Go to the **Deploy** drop-down menu, and select **→ Manage Deployment**

Deploy Menu

2. **Configuration:** The Configuration window will pop up

3. **Select Type:** Under the Menu Select **Type**, Select **Web app**

4. **New description:** Provide a brief and clear explanation of the script's purpose  
   Example: "automates data entry and processing for Google Sheets"

5. **Web app:** Write the email you used to complete this process in the Web App section

6. **Who has access:** Using the drop-down menu, choose **Anyone**. Selecting "Anyone" allows any user who visits the web app link to execute it, making it easier to share without requiring a Google credential

Configuration Window Settings

### Step V: Authorization Process

1. **New Deployment:** Click on the **"Authorize Access"** button

Authorize Access Button

2. **Authorization:** Once you click Authorize access, the AQS Data Spreadsheet Logger screen will pop up requesting access to your Google Account

3. **Security Warning:** Another screen will pop up - click on **Go to AQS Data Spreadsheet Logger (unsafe)**

Authorization Dialog
⟵ Click the **Allow** button

Security Warning Screen

↑ Click Go to AQS Data Spreadsheet Logger (unsafe)

4. **Advanced Options:** Ignore this message - Google hasn't verified this app. Go to the bottom of the page and click on **Advanced**

Advanced Security Options

Final Authorization Screen

---

## Troubleshooting

### Script Editor Access Issues

**Problem:** If you get an error message window when trying to access the Script Editor

Error Message Example

Account Selection Error
⟵ **Default email**

**Cause:** You are most likely not using your default Google account for your spreadsheet

Notice that the *Default email* is different than the one that appears on the error message.

**Solution:**
- You must sign out of your default Google account to correct this issue
- This may require signing out of all your accounts, as Google doesn't allow signing out of only one account when multiple accounts are signed in simultaneously
- Once you have signed out, you can sign in to your default account

**Steps to resolve:**
1. Sign in to the account you are using to access your Google Sheets
2. Once you sign into that account, return to the spreadsheet
3. Try opening the script editor again

### Common Issues and Solutions

- **Permission Errors:** Ensure you're consistently using the same Google account throughout the process
- **Spreadsheet ID Errors:** Double-check that you copied the complete ID string from the URL
- **Authorization Problems:** Follow the security warning steps carefully, even if they appear "unsafe"

---

## Additional Resources

- **[Google Apps Script Documentation](https://developers.google.com/apps-script)**
- **[Community Sensor Lab GitHub Repository](https://github.com/Community-Sensor-Lab/Air-Quality-Sensor)**
- **[Google Sheets API Reference](https://developers.google.com/sheets/api)**

---

## Next Steps

Once your deployment is complete, your Air Quality Monitor will be configured to automatically send data to your Google Spreadsheet. The system will collect, record, and store air quality data in real time, making it accessible for analysis and sharing with your community.

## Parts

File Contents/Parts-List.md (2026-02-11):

## **Featherwing Components**
|||||
| ---- | ---- | ---- | ---- |
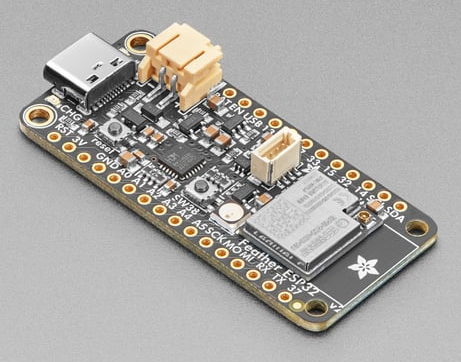
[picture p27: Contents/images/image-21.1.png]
Feather M0 WiFi
| NEW! Feather ESP32 V2 |  | Microcontroller and Wifi<br>It is the CPU of the system. | [Adafruit Store](https://www.adafruit.com/product/5400) |
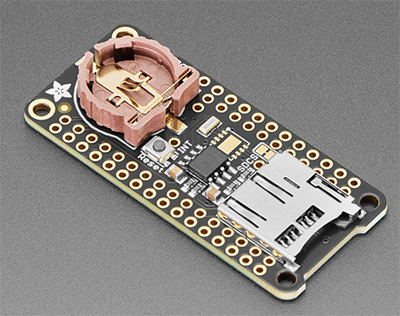
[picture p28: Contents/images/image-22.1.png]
Featherwing Logger
| Adalogger FeatherWing<br>MicroSD and Clock |  | Real-time Clock and MicroSD Reader. It is the hard drive and data storage of the device. | [Adafruit Store](https://www.adafruit.com/product/2922) |
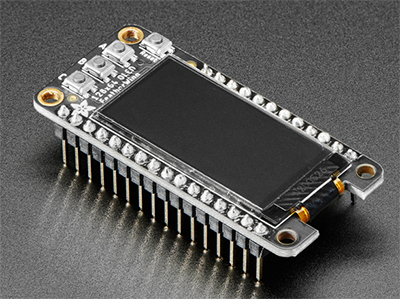
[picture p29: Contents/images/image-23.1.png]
Featherwing OLED
| Featherwing OLED 128x64 |  | Display. It is the computer screen. | [Adafruit Store](https://www.adafruit.com/product/4650) |

## **Sensors**
|||||
| ---- | ---- | ---- | ---- |
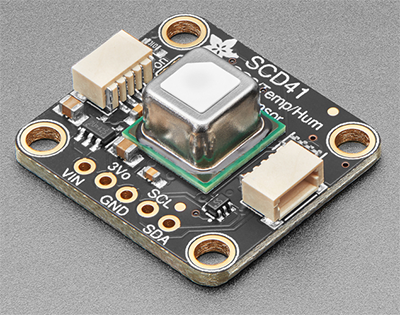
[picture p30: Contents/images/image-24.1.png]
Adafruit SCD41 CO2
| Adafruit SCD41 CO<sub>2</sub> |  | CO<sub>2</sub> NDIR Sensor | [Adafruit Store](https://www.adafruit.com/product/5190) |
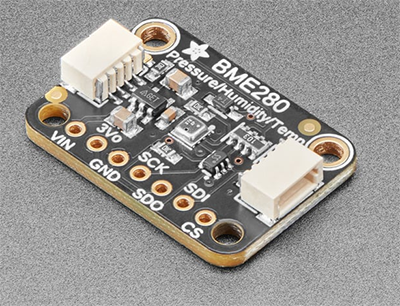
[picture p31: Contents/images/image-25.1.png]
BME280 Sensor
| BME280 TPRH |  | Temperature, Pressure, Relative Humidity Sensor | [Adafruit](https://www.adafruit.com/product/2652) |
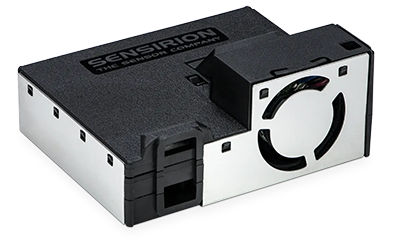
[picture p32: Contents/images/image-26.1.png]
Sensirion SEK-SEN5X
| Sensirion SEN5X |  | Particulate Matter PM, VOCs, NOX Sensor | [DigiKey](https://www.digikey.com/en/products/detail/sensirion-ag/SEK-SEN5X/15903862) |

## **Additional Parts**

|||||
| ---- | ---- | ---- | ---- |
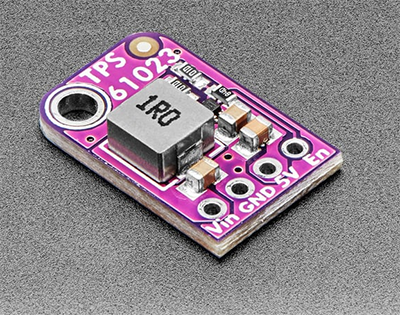
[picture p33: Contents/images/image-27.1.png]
MiniBoost 5V
| MiniBoost 5V |  | 3.3 to 5 Voltage Converter | [Adafruit](https://www.adafruit.com/product/4654) |
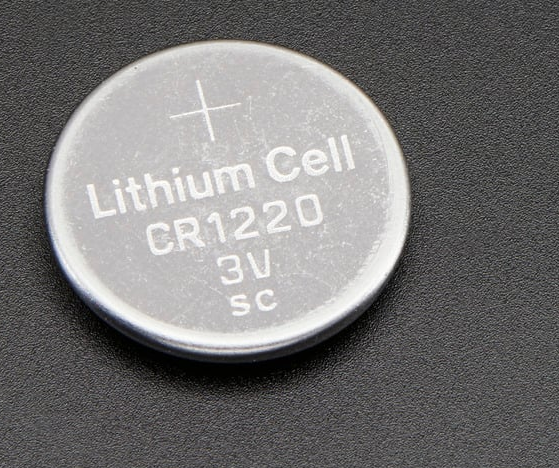
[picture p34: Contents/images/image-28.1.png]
Battery Coin cr1220
| Coin Battery CR1220 |  | Battery for RTC| [Adafruit](https://www.adafruit.com/product/380) |
| Micro SD<br>4GB min | Micro SD | Permanent Data Storage on the Device | [DigiKey](https://www.digikey.com/en/products/detail/delkin-devices-inc/USDCOEM-16GB/13882332) |
| 4 Pin Headers | 4 Pin Headers | For MiniBoost 3.3 to 5 Volt. Converter | [DigiKey](https://www.digikey.com/en/products/detail/sullins-connector-solutions/PPTC041LFBN-RC/810144) |
| 5 Pin Headers | 5 Pin Headers | For the SCD41 CO<sub>2</sub> sensor | [DigiKey](https://www.digikey.com/en/products/detail/sullins-connector-solutions/PPTC051LFBN-RC/807239) |
| 6 Pin Headers | 6 Pin Headers | For the Particulate Matter Sensor | [DigiKey](https://www.digikey.com/en/products/detail/würth-elektronik/61300611821/16608482) |
| 7 Pin Headers | 7 Pin Headers | 7 Pin Header for BME280 and SCD30 | [DigiKey](https://www.digikey.com/en/products/detail/sullins-connector-solutions/PPTC071LFBN-RC/810146) |
| 12 Pin Headers | 12 Pin Headers | For the Feather boards | [DigiKey](https://www.digikey.com/en/products/detail/sullins-connector-solutions/PPTC121LFBN-RC/807231) |
| 16 Pin Headers | 16 Pin Headers | For Feather boards | [DigiKey](https://www.digikey.com/en/products/detail/sullins-connector-solutions/PPTC161LFBN-RC/810154) |
| Feather Stacking Headers Set | Feather Stacking Header Set | Stacking headers for Feather ESP32 V2 | [Adafruit](https://www.adafruit.com/product/2830) |
| Grove Female Header DIP-4P-2.0mm<br>(optional) | Grove Female Header | i2c Grove Connector | [Seeed Studio](https://www.seeedstudio.com/Grove-Universal-4-pin-connector.html) |
| Custom PCB CSL<br>(Gerber files [here]( ../E_CAD  )) | CSL_AQS_V1 PCB Board | PCB Board | [PCBWay](https://www.pcbway.com/) |
| PVC Tube<br>Charlotte type is best | PVC Tube | 3" ID, 7" Length Tube | [Home Depot](https://www.homedepot.com/p/Charlotte-Pipe-3-in-x-2-ft-PVC-DWV-Sch-40-Pipe-PVC073000200HA/100533056) |
| PVC Cap | PVC Cap | PVC Cap 3 Inch Diameter | [Home Depot](https://www.homedepot.com/p/3-in-PVC-DWV-Cap-PVC001161000HD/203393254) |
| Type C Cable | Type C Cable | USB-C to USB-A or USB-C | [Amazon](https://www.amazon.com/Ruaeoda-Micro-Android-Charger-Gold-Plated/dp/B0D7RZJSPS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) |
| Grainger #6 Screw | Grainger #6 Screw Socket Head | 6-32 x 1/2'' Socket Head Screw | [McMaster-Carr](https://www.mcmaster.com/catalog/130/3555/92196A146) |
| 6#-32 Lock Nuts | 6#-32 Lock Nuts | 6#-32 Lock Nuts | [Amazon](https://www.amazon.com/dp/B09V2SMKCS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) |
| 11mm, M2.5 Standoffs | 11mm, M2.5 Standoffs | 100 Pcs M2.5 11mm Standoffs | [Amazon](https://www.amazon.com/dp/B0BK99T8S4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) |
| Hex Nuts, M2.5x0.45mm | Hex Nuts, M2.5x0.45mm | 100 Pcs M2.5x0.45mm Hex Nuts | [Amazon](https://www.amazon.com/dp/B07H3WGLJN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) |
| M2.5x6mm Screws | M2.5x6mm Screws | 100 Pcs M2.5x6mm Screws | [Amazon](https://www.amazon.com/dp/B01B1PGR22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) | |

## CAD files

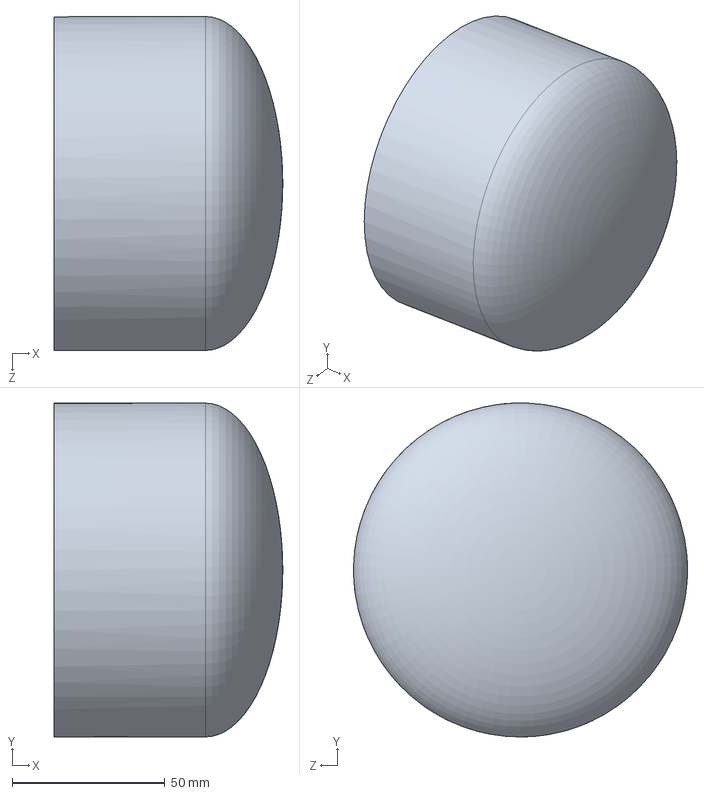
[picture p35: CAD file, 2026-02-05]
M_CAD/M_CAD-Inventor2025/Air Quality Board Mount/3in End Cap.SLDPRT
74.9 x 109.4 x 109.5 mm

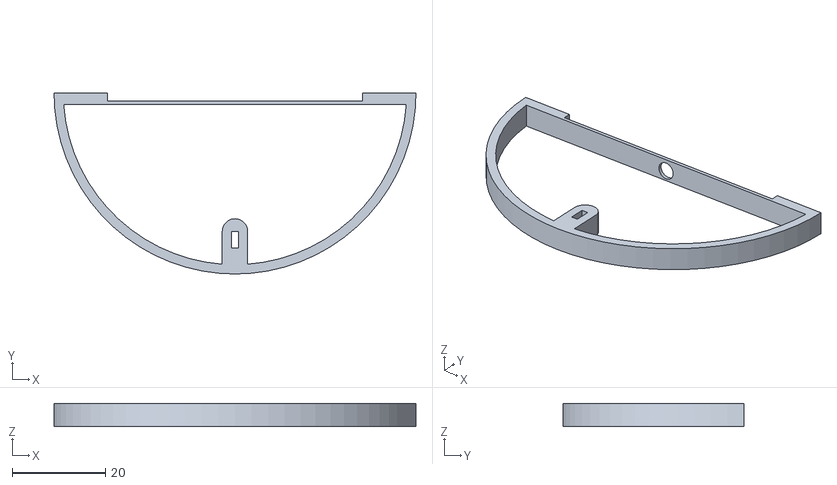
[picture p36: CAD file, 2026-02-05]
M_CAD/M_CAD-Inventor2025/Air Quality Board Mount/AQS Mount V1/Siding Lock.stl
77.5 x 38.8 x 5.00

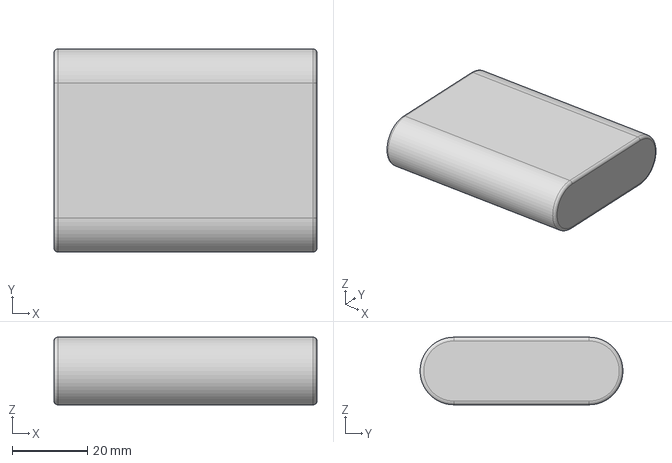
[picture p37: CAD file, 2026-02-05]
M_CAD/M_CAD-Inventor2025/Air Quality Sensor/353 6600mAh Battery.step
70.0 x 54.0 x 18.0 mm

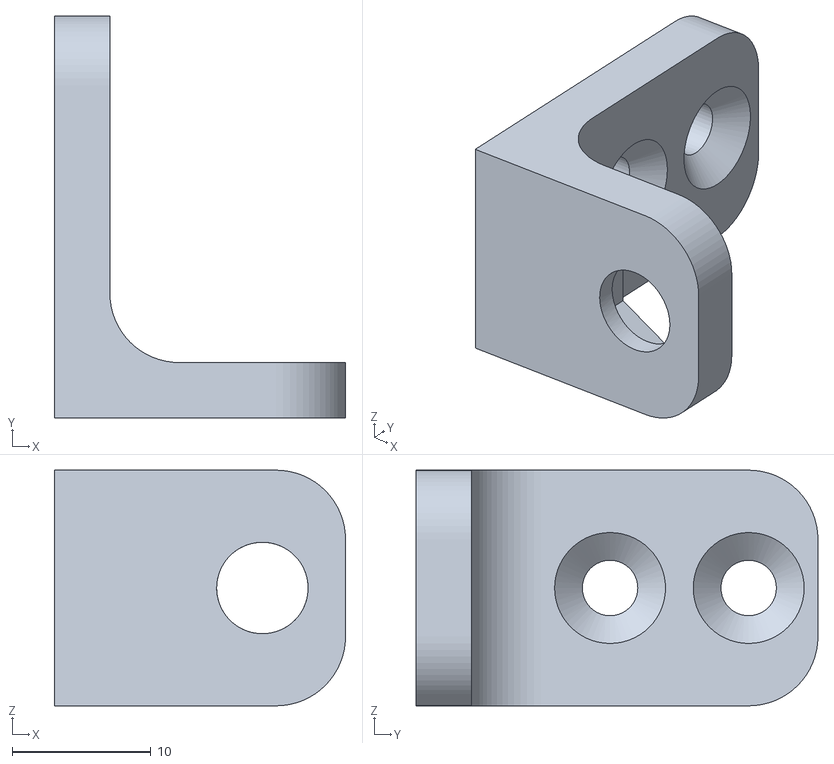
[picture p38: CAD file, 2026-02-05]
M_CAD/M_CAD-Inventor2025/STL Files/AntennaWallMount.stl
21.0 x 29.0 x 17.0

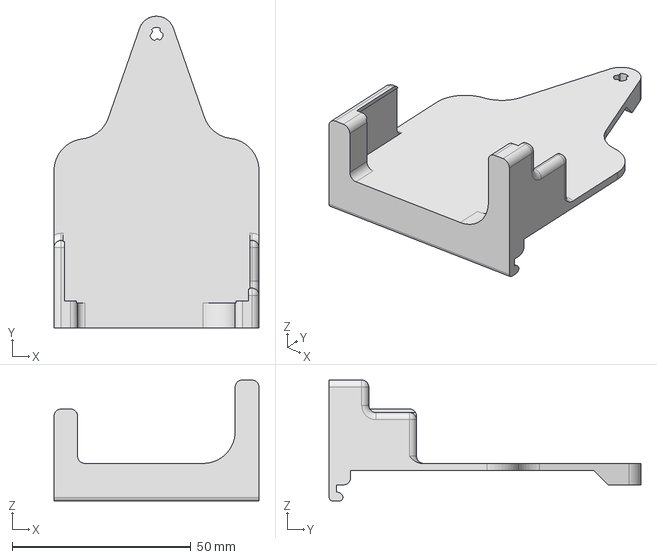
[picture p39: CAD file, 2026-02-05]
M_CAD/M_CAD-Inventor2025/STP Files/SEN5X Mount V4.stp
57.3 x 87.1 x 33.8 mm

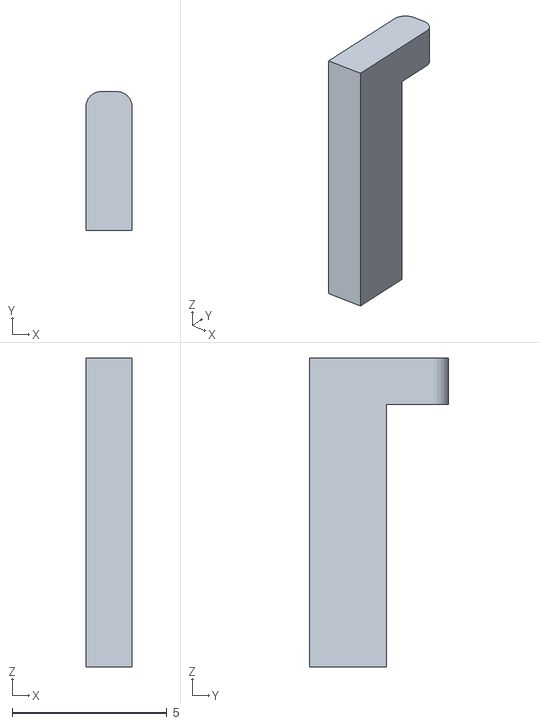
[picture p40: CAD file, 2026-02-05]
M_CAD/M_CAD-Inventor2025/Air Quality Board Mount/AQS Mount V1/Key.stl
1.50 x 4.50 x 10.0

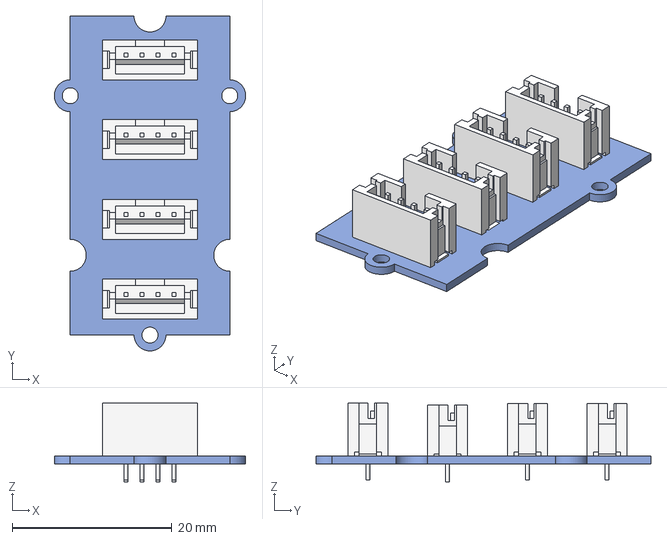
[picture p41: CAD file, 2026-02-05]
M_CAD/M_CAD-Inventor2025/Air Quality Sensor/Grove I2C hub.step
24.0 x 42.0 x 9.85 mm
B4B-PH-SM4-TB x 4
PCB Board

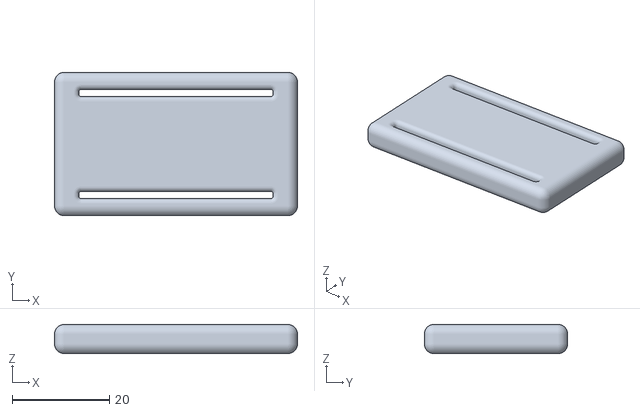
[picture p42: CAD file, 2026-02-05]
M_CAD/M_CAD-Inventor2025/STL Files/Trimming Template.stl
50.0 x 29.5 x 6.00

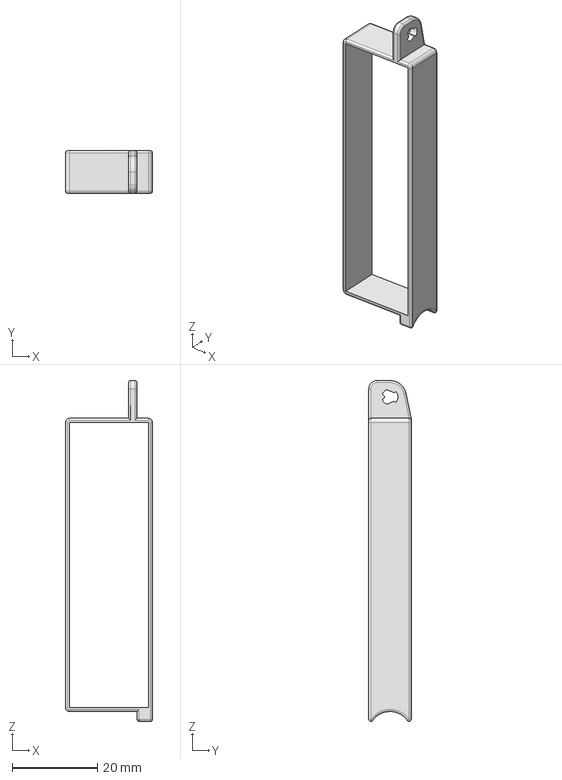
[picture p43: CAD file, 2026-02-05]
M_CAD/M_CAD-Inventor2025/STP Files/Battery Mount V1.stp
20.5 x 10.0 x 80.2 mm

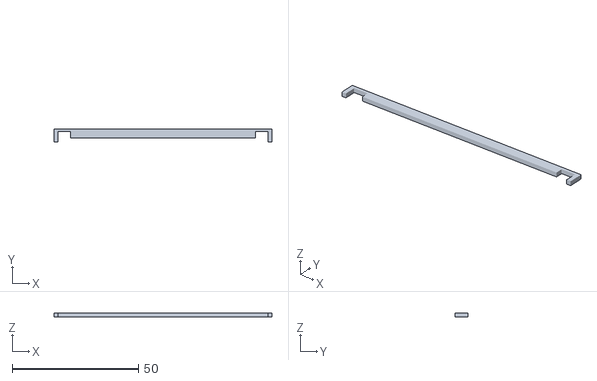
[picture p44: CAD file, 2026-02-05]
M_CAD/M_CAD-Inventor2025/Air Quality Board Mount/AQS Mount V1/Bar.stl
86.5 x 5.00 x 1.50

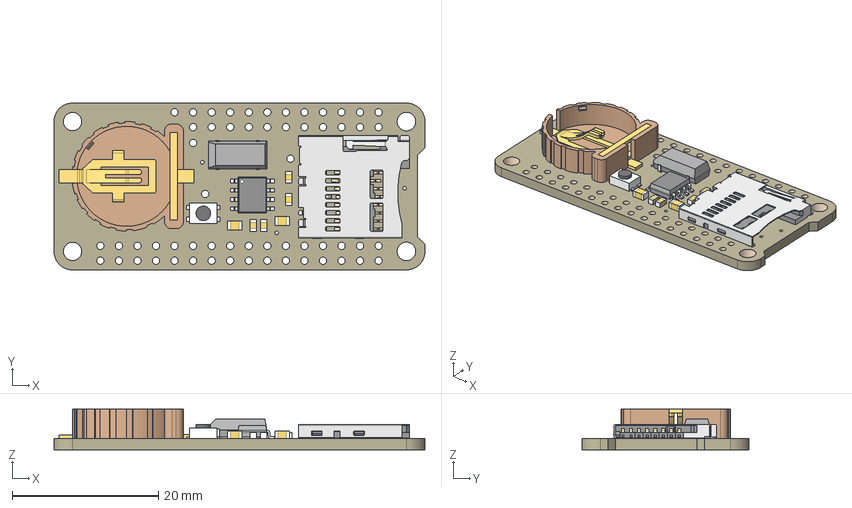
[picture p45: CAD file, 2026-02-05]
M_CAD/M_CAD-Inventor2025/Air Quality Sensor/2922 FeatherWing Adalogger.step
50.8 x 22.9 x 5.57 mm
Board
microsd
KMR2
PCF8523T
32khz
1K x 4
cr1220
10uF x 2

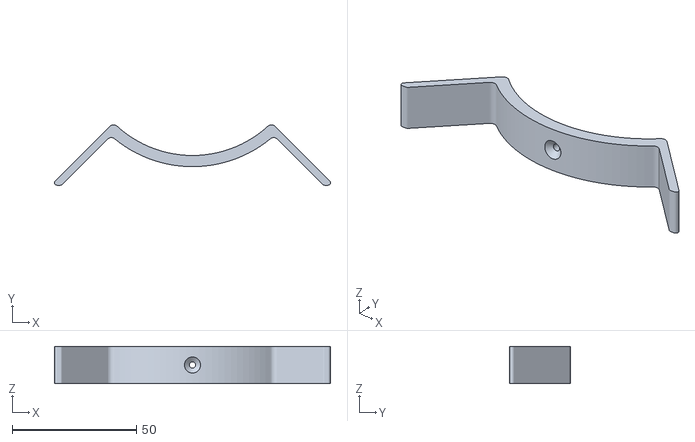
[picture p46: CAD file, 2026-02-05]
M_CAD/M_CAD-Inventor2025/STL Files/Horizontal Base V2.stl
111.2 x 24.4 x 15.0

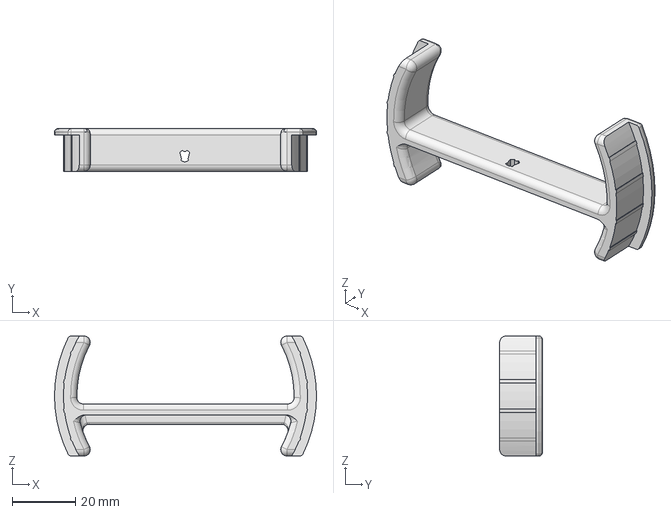
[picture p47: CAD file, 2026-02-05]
M_CAD/M_CAD-Inventor2025/STP Files/AQS Mount V6.stp
83.0 x 13.5 x 38.0 mm

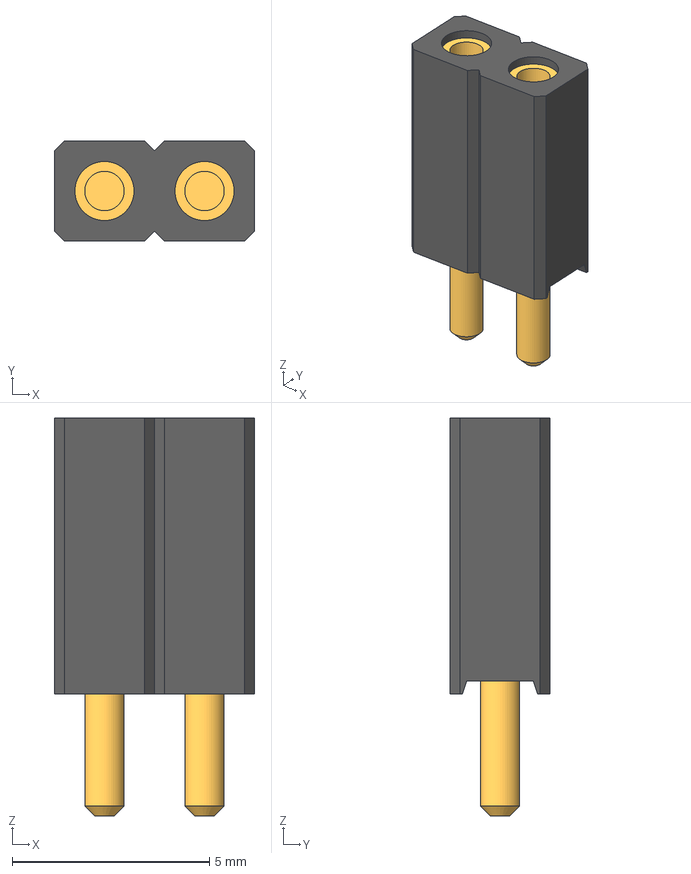
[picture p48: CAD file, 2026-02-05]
M_CAD/M_CAD-Inventor2025/Air Quality Sensor/head_f_2p.step
5.08 x 2.54 x 10.1 mm

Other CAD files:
M_CAD/M_CAD-Inventor2025/STL Files/PCB Soldering Stand for Ultimaker 5.stl
M_CAD/M_CAD-Inventor2025/STP Files/Solar Board Mount V1.stp
M_CAD/M_CAD-Inventor2025/Air Quality Sensor/4654 MiniBoost 5V.step
M_CAD/M_CAD-Inventor2025/STL Files/Horizontal Base (Print 2).stl
M_CAD/M_CAD-Inventor2025/Air Quality Board Mount/3in End Cap/3in End Cap.ipt
M_CAD/M_CAD-Inventor2025/Air Quality Board Mount/3in End Cap/OldVersions/3in End Cap.0002.ipt
M_CAD/M_CAD-Inventor2025/Air Quality Board Mount/AQS Assembly.iam
M_CAD/M_CAD-Inventor2025/Air Quality Board Mount/AQS Mount V1/Bar.ipt
M_CAD/M_CAD-Inventor2025/Air Quality Board Mount/AQS Mount V1/Board.ipt
M_CAD/M_CAD-Inventor2025/Air Quality Board Mount/AQS Mount V1/Key.ipt
M_CAD/M_CAD-Inventor2025/Air Quality Board Mount/AQS Mount V1/Mount.iam
M_CAD/M_CAD-Inventor2025/Air Quality Board Mount/AQS Mount V1/OldVersions/Assembly.iam
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

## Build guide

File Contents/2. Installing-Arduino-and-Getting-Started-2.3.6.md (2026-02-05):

**Installing Arduino**  
To get started, make sure the **Arduino application** is installed on your computer or laptop. If it hasn't been installed yet, visit the [Arduino website](https://www.arduino.cc/en/software/) to download and install it.  
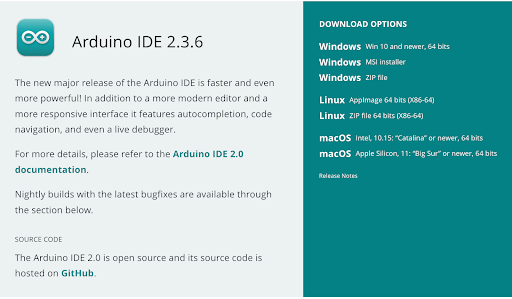
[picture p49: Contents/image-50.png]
Arduino IDE Download Page


# Arduino Download Instructions

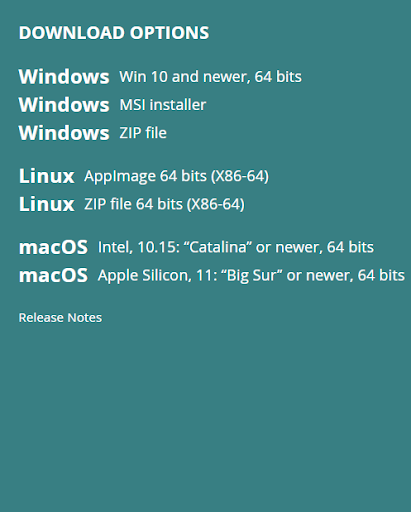
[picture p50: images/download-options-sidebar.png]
Arduino Download Options


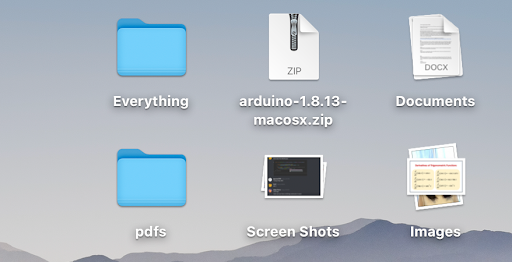
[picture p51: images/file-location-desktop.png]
Windows Download Options


On the Arduino download page, choose the version that matches your computer's operating system.

## For Windows users:

- **Do not** select the **.zip file** option.
- Instead, choose either **"Windows 64-bit App"** or **"Windows Installer"** for proper installation.

## After the download is complete:

- **On a Mac**: The zip file may appear on your **Desktop** or in your **Downloads** folder.
- **On Windows**: The zip file will typically be found in your **Downloads** folder or on your **Desktop**.

  **On a Mac**:

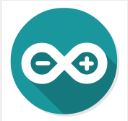
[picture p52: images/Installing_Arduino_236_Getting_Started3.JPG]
Mac Installation
  

* Open the downloaded zip file.  
* The Arduino application will appear—**drag it into your  Applications folder** to install it.

**On Windows**:

* Open the file you downloaded—either the **64-bit App** or the **MSI Installer**.  
* Follow the prompts to complete the installation.

---

**Arduino Environment**

Now that the Arduino application has been installed successfully, open it. The Arduino IDE should look something like this:

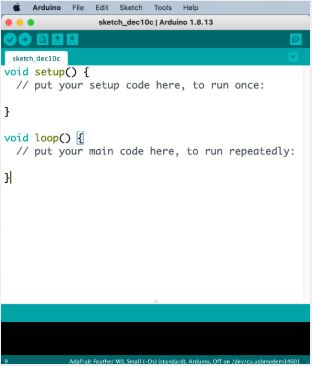
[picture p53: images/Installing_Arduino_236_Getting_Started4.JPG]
Arduino IDE Interface


- This is where the code is written to run Arduino programs
- Any error messages will appear **in the margins of the black console window** when you run your code

## Installing Required Packages and Libraries

Before running any programs on your **Arduino**, you must install a few essential packages and libraries. Without these, the Arduino won't be able to execute your code.

### Install Adafruit Board Package

This initial installation is required to give the Arduino application access to specific Adafruit libraries you'll need.

1. **Access Preferences**
   - Click on the Arduino drop-down menu and select Preferences (or Arduino → Settings)
   
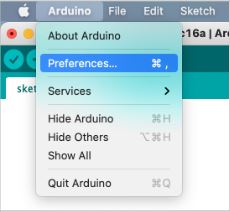
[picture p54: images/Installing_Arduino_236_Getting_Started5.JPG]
Arduino Preferences
   
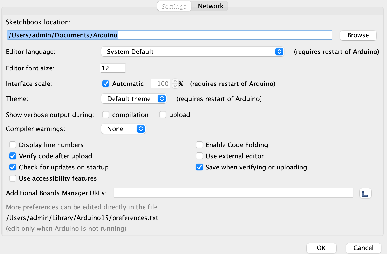
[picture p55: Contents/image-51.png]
Settings Menu
   

2. **Add Board Manager URL**
   - Copy this link: **https://adafruit.github.io/arduino-board-index/package_adafruit_index.json**
   - Paste the link in "Additional Boards Manager URLs"
   
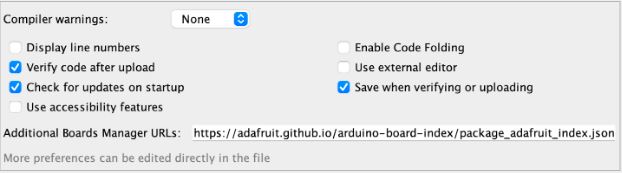
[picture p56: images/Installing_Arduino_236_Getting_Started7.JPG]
Board Manager URL
   

3. **Apply Settings**
   - Click "Ok" and close the Arduino Application

4. **Install Adafruit Boards**
   - Go to Tools → Board → Boards Manager
   
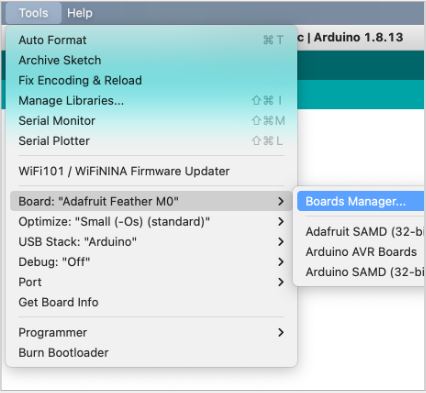
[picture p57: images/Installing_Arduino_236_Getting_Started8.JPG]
Boards Manager
   
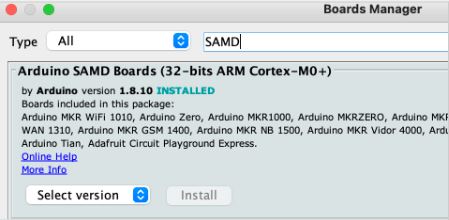
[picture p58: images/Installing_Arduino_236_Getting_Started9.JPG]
Boards Manager Window
   

5. **Close Boards Manager**
   - Once you are done downloading the necessary boards, close the Boards Manager window
   
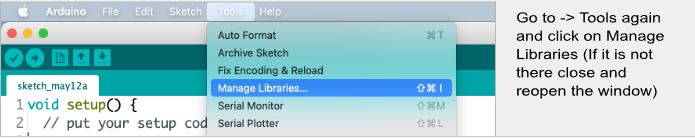
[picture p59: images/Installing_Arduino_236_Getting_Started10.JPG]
Close Boards Manager
   

### Install Required Libraries

1. **Access Library Manager**
   - Go to Tools → Manage Libraries

2. **Install WiFi101 Library**
   - In the search bar type "WiFi101" and install the library called "WiFi101"
   
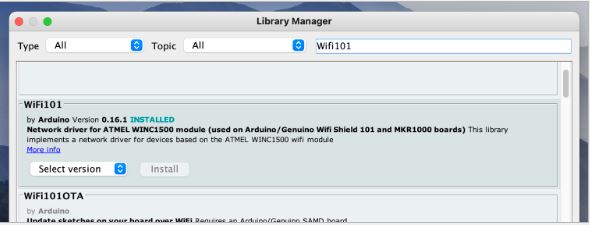
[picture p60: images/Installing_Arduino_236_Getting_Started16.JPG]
WiFi101 Library
   

3. **Install Additional Libraries**
   
   Repeat the search and install process for the following libraries (for libraries that require other libraries to be installed, click install all when prompted):

   - Adafruit Sleepy Dog
   - SparkFun SCD4X Arduino Library
   - Adafruit GFX
   - Adafruit SSD1306
   - Adafruit BME280
   - Adafruit SH110X
   - Sensirion I2C SEN5X
   - flashstorage
   - WiFi101
   - Honeywell TruStability SPI

4. **Install RTClib Library**
   - Download RTClib from [Github](https://github.com/adafruit/RTClib)
   - In Arduino IDE: Select Sketch → Include Library → Add .ZIP Library
   - Open the ZIP folder that you have just downloaded

**Installation Complete!** You now have all the necessary components installed.

---

## Connecting and Testing Your Arduino

### Hardware Connection

1. **Connect Arduino to Computer**
   - Plug in your Arduino to your laptop using a Micro-USB Cable
   - If you do not have a USB port on your computer, you will need an adapter
   
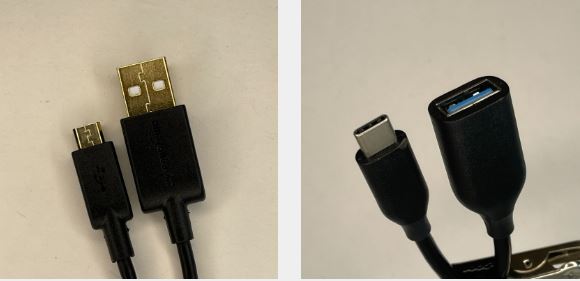
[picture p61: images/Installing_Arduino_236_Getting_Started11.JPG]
Arduino Connection
   

### Software Configuration

2. **Select the Correct Port**
   - Launch Arduino IDE and select the correct port with the dropdown menu
   
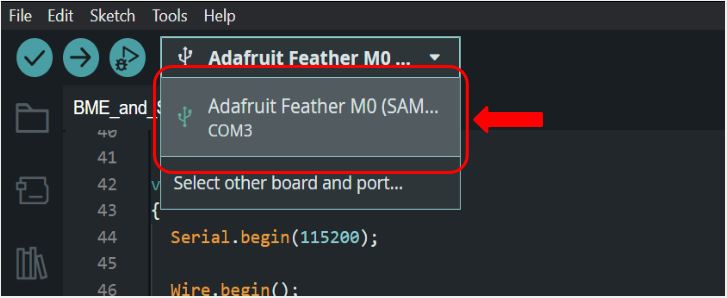
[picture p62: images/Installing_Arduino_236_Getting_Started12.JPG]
Port Selection
   

### Code Compilation and Upload

3. **Compile Your Code**
   - When you have the correct port selected and you are ready to compile code to your Arduino, first compile the code to check for any errors beforehand
   
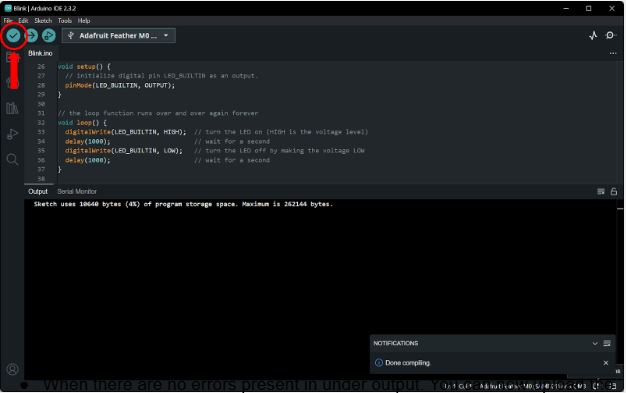
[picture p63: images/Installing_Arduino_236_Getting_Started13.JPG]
Compile Code
   

4. **Upload to Arduino**
   - When there are no errors present in the output, you can now upload the code to your Arduino
   
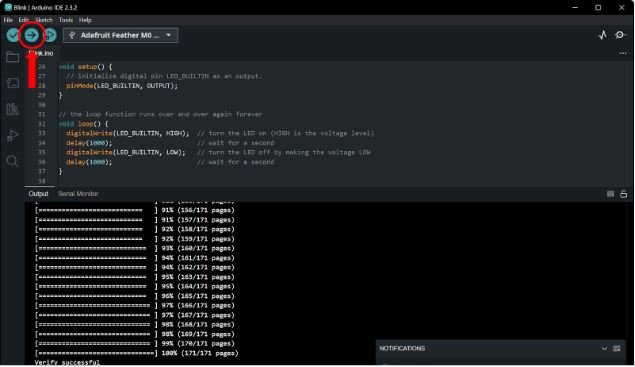
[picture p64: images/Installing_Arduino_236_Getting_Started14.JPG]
Upload Code
   

## Testing Your Setup

### Running the Blink Example

Now that you have all the libraries downloaded, you can test the connection between the sensor and your computer.

1. **Load Blink Example**
   - Go to File → Examples → Basics → Blink to pull up the blink code
   - This code can be used to test if the sensor is connected to your computer and can have code uploaded to it
   
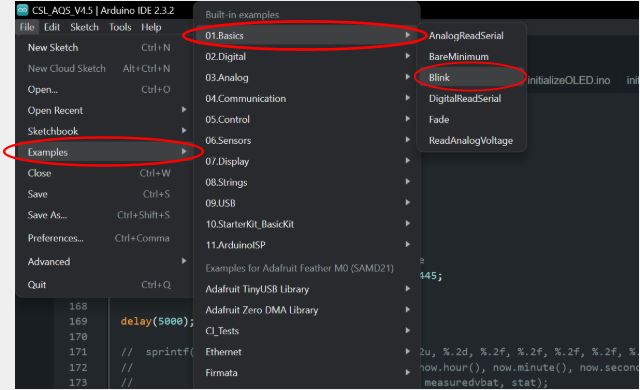
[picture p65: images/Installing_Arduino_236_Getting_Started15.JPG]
Blink Example
   

2. **Test the Connection**
   - Upload the code and look at the sensor when the code finishes uploading
   - Check if the light is blinking to confirm successful connection

---

## Troubleshooting

If you encounter issues:
- Ensure the correct port is selected
- Check that all required libraries are properly installed
- Verify your Arduino is properly connected via USB
- Review any error messages in the console window for specific guidance

Your Arduino setup is now complete and ready for sensor projects!

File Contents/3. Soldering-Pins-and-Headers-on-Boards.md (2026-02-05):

# Component Soldering

## Materials

* Breadboard  
* [BME 280](https://www.adafruit.com/product/2652) - Temperature, humidity & pressure sensor with high accuracy
* [SCD 41](https://learn.adafruit.com/adafruit-scd-40-and-scd-41) - Photoacoustic 'true' CO2 sensor that measures CO2 PPM composition
* 5V Booster  
* SEN55  
* JST Cables  
* Featherwing OLED  
* Featherboard M0 WIFI  
* Adalogger Featherwing  
* Two Feather Stacking Headers Set  
* Micro SD  
* Coin Battery (cr1220)

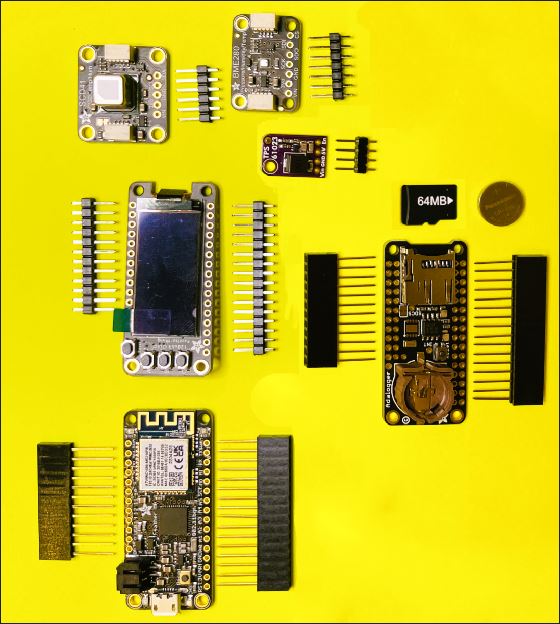
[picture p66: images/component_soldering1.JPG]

*All components laid out for inventory check*

## Tools

* [Soldering Iron](https://www.adafruit.com/category/84) - Temperature-controlled recommended for precision work
* Soldering Wire  
* Wet Sponge  
* [Brass Wire Wool](https://www.adafruit.com/product/1172) - For cleaning soldering iron tip
* Fan/Exhaust  
* [Magnifier](https://www.adafruit.com/product/291) - Helps with precision component placement
* Riser Trimming Tool  
* Clipping Tool

## Step 1: Soldering SCD 41, BME 280, 5V Booster, and Featherwing OLED

* Place pin headers evenly spaced out onto the breadboard.  
* Place each sensor board onto the respective pins:  
  * **OLED**: When connecting the OLED to the breadboard, it can't be pushed all the way because pin headers stick out. This allows the OLED to lay perfectly on the black part of the pinheads.

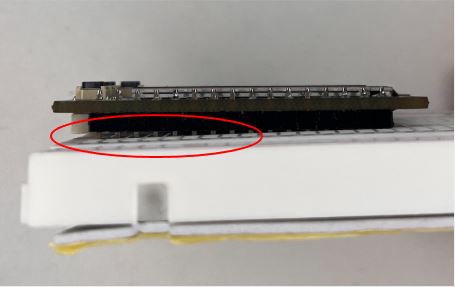
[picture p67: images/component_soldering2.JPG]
   
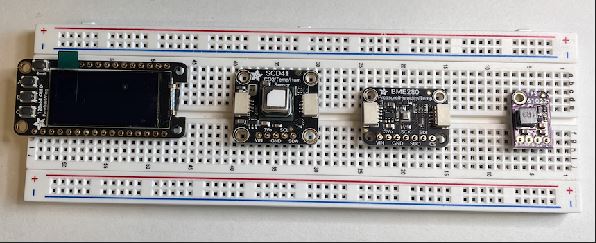
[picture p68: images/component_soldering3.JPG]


* Make sure the [SCD41](https://www.bosch-sensortec.com/products/environmental-sensors/humidity-sensors-bme280/), [BME280](https://learn.adafruit.com/adafruit-scd-40-and-scd-41), and 5V Booster are connected straight on the breadboard.   
  * This can be accomplished by soldering one pin at one end and then applying the heat to move it in place with your other hand.  
  * You can also balance it before soldering by pushing it down with one finger on the pin side to keep it straight.  
* Once you have it straightened properly, complete the soldering for each pin.

## Step 2: Soldering Feather M0 Stacking Header and Logger Stacking Header

* For this part, have your OLED in hand, for it will make it easier to solder.  
* Attach a set of stacking headers to the OLED, then place the Adalogger Featherwing on top faced down.

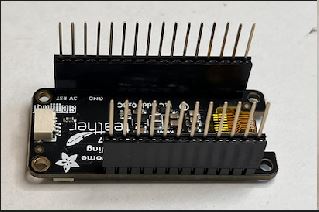
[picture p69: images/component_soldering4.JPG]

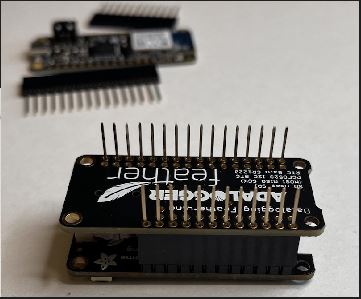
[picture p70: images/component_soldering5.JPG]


* Now start by soldering one end at a time.

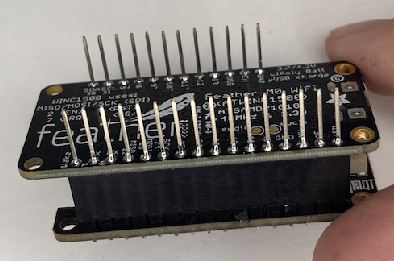
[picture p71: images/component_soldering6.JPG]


* Repeat the same steps for the Featherboard M0 WiFi.

## Step 3: Trimming the Stacking Headers

* Place the Riser Trimming tool in between the stacking headers.

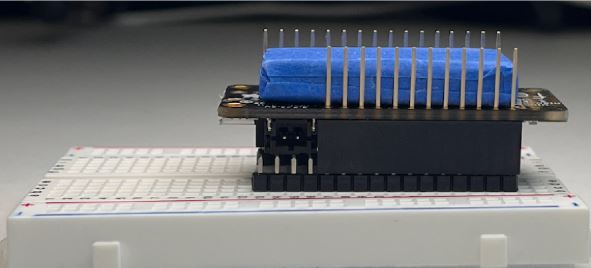
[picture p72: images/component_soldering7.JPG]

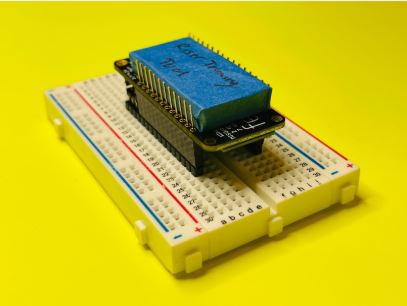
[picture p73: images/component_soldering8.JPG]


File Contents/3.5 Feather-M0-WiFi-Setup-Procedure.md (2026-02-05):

# Setup for a New Adafruit Feather M0 with WiFi (WINC1500)

This step is a one-time procedure for new, out of bag, [FeatherM0 WiFi boards](https://www.adafruit.com/product/3010) (Adafruit).

## ⚠️ Important Requirements

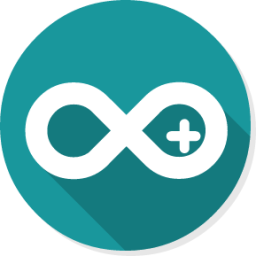
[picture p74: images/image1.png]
Arduino IDE V1.x
**NOTE: This procedure only works with the old Arduino IDE that has the round icon  **(V1.x)**

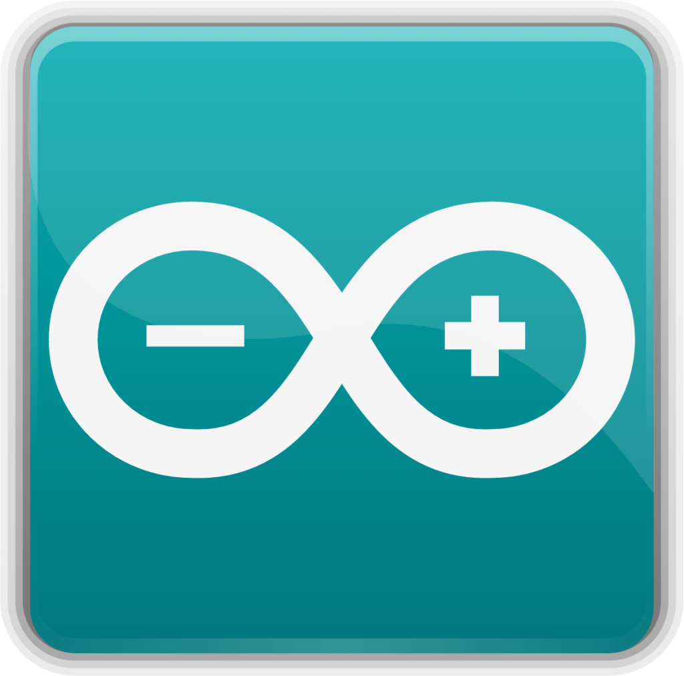
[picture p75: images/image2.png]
Arduino IDE V2.x
**It does not work on the new IDE with the square icon  **(V2.x)**

---

## Step-by-Step Setup Process

### 1. Prepare Your Development Environment

Open the old [Arduino IDE (V1.x)](https://www.arduino.cc/en/software/OldSoftwareReleases). If you don't have it installed, download and set it up. You can have both versions on your computer.

### 2. Install Required Libraries

Check that the latest [WiFi101 library](https://github.com/arduino-libraries/WiFi101) is installed. If not, install or update it through the Library Manager.

### 3. Load the Firmware Updater Sketch

Open the following arduino sketch: **Examples > WiFi101 > FirmwareUpdater**

### 4. Configure for Feather M0 WiFi

In the example, add the line of code shown below at line 43:

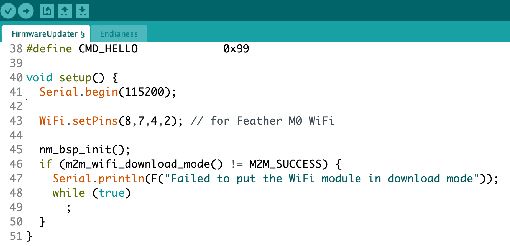
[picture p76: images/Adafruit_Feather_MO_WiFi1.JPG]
Code modification for Feather M0 WiFi


*This instruction sets the control pins in the program to work with the Feather M0 Wifi board*

### 5. Upload the Firmware Updater

Upload the code to your board. **Do not open the Serial Monitor.**

---

## Firmware Update Process

### 6. Open the Firmware Updater Tool

At the top of the Arduino IDE window, go to **Tools > WiFi101 / WiFiNINA Firmware Updater** as shown here:

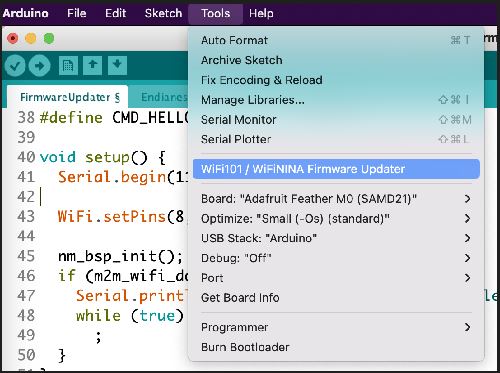
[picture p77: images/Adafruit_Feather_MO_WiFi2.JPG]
Accessing the firmware updater tool


You will get the following window:

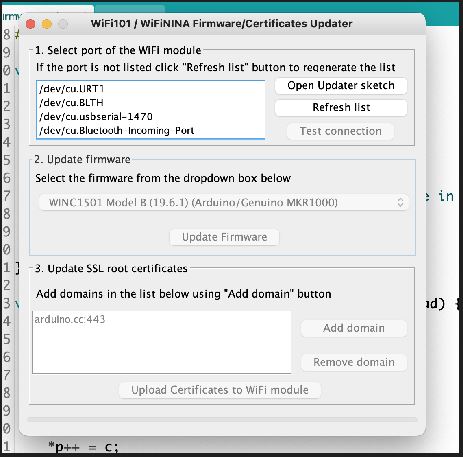
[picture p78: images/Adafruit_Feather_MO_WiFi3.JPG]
Firmware updater interface


### 7. Test Connection

Test the connection between your computer and the FeatherM0WiFi with **1. Select port of the WiFi module.**

### 8. Update Firmware

**2. Update Firmware.** Select the latest version of the [WINC1501 Model B](https://www.microchip.com/en-us/product/ATWINC1500) (19.6.1 in the picture above).

### 9. Configure SSL Certificates

**3. Update SSL root certificates.** 

- Select **Add domain**
- Enter [**www.google.com**](http://www.google.com)
- Repeat and enter **script.google.com** 

Your window should look like this:

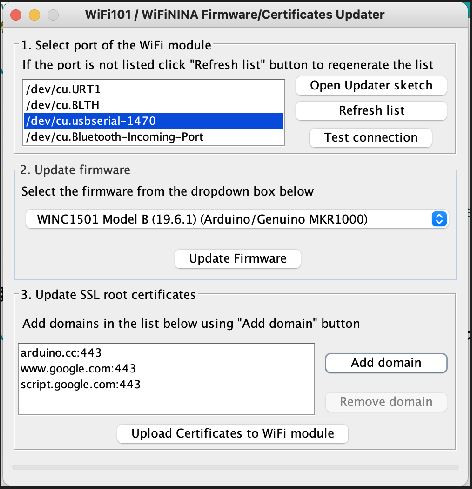
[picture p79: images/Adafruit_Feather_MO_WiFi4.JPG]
SSL certificate configuration


### 10. Complete the Setup

Select **Upload Certificates to WiFi module** and the Feather M0 WiFi board is ready for use with Google.

---

## Additional Resources

**More info at:** [Updating Firmware](https://learn.adafruit.com/adafruit-feather-m0-wifi-atwinc1500/updating-firmware)

## Troubleshooting

If you encounter issues during this process:
- Ensure you're using Arduino IDE V1.x (not V2.x)
- Verify the WiFi101 library is properly installed
- Check that your board is properly connected and recognized by your computer
- Make sure you don't have the Serial Monitor open during firmware upload

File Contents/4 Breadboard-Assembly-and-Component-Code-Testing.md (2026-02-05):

# How to Assemble Air Quality Sensor Boards

This guide walks you through assembling your air quality sensor, focusing on attaching the boards onto the breadboard and testing each component systematically. Make sure that sensors and boards (with the exception of the SPS30 PM 2.5 Sensor) are soldered to the appropriate headers.

## 📋 Materials Required

**Note:** Refer to the complete [Parts List](https://github.com/Community-Sensor-Lab/Air-Quality-Sensor/blob/master/README.md#Parts-List-) on GitHub for detailed specifications.

### Essential Components:
- [Breadboard](https://www.adafruit.com/product/239) 
- Soldered CPU & WiFi Board ([Adafruit Feather M0](https://www.adafruit.com/product/3010))
- Soldered OLED Display Board
- Soldered Logger & Clock Board ([Adalogger FeatherWing](https://www.adafruit.com/product/2922))
- [Coin Battery CR1220](https://www.adafruit.com/product/380)
- [SD card](https://www.adafruit.com/product/1294) (formatted)
- [Micro-USB to USB cable](https://www.adafruit.com/product/592) (or alternatively, a battery pack)
- Jumper Wires ([Premium Male/Male](https://www.adafruit.com/product/758))

### Sensors:
- Soldered [BME 280](https://www.adafruit.com/product/2652) (Temperature, Humidity, Pressure)
- Soldered [SCD41](https://www.adafruit.com/product/5190) (CO2)
- [SEN55](https://www.sensirion.com/products/catalog/SEN55/) (All-in-one environmental sensor)

### Tools Needed:
- Computer with Arduino IDE installed
- [SD Card Reader](https://www.adafruit.com/product/939) (if not built into computer)
- [SD Card Formatter](https://www.sdcard.org/downloads/formatter/) software

---

## 🚀 Getting Started

### Initial Setup

1. **Prepare your workspace:** Have a clear breadboard in front of you. This will be your main assembly platform.

2. **Organize components:** Keep your FeatherM0 CPU & WiFi board nearby - this is the central hub that all sensors will connect to.

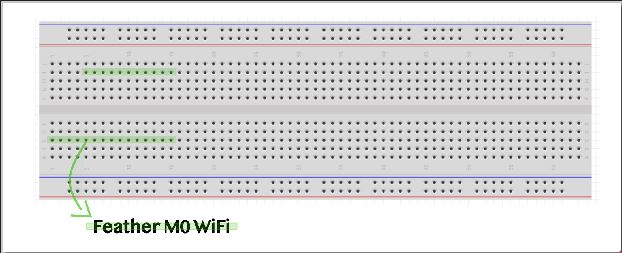
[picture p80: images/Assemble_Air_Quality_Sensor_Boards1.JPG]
breadboard setup


---

## ⚙️ Preliminary Configuration

### Setting Time and Date on Arduino Real Time Clock (RTC)

**Important:** Complete this step before assembling sensors to ensure accurate timestamping.

1. **Install Adalogger:** Insert Adalogger on top of the Feather M0
2. **Open RTC example code:** 
   - Navigate to Examples → RTCLib → Open pcf8523
3. **Modify the code:** Comment out lines 21, 22, and 34 (add `//` at the beginning of each line)

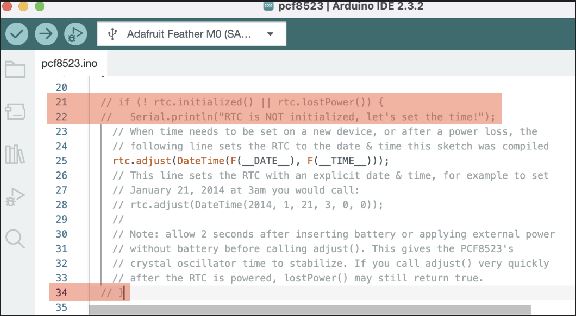
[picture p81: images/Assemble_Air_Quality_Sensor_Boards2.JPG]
RTC Setup


4. **Upload the code:**
   - Select correct board: Tools → Board → Adafruit SAMD boards → Adafruit Feather M0
   - Select correct port: Tools → Port → Select the one with sensor
   - Click Upload

5. **⚠️ Critical:** DO NOT RESET/RESTART THE ARDUINO after uploading as this will reset the clock to compilation time. Instead, proceed directly to upload the main AQI code.

### SD Card Preparation

1. **Download formatter:** Get the official SD card formatter from [https://www.sdcard.org/downloads/formatter/](https://www.sdcard.org/downloads/formatter/)

2. **Format the card:** 
   - Connect SD card to computer (use SD card reader if necessary)
   - Open SD card formatter application
   - Format using recommended settings

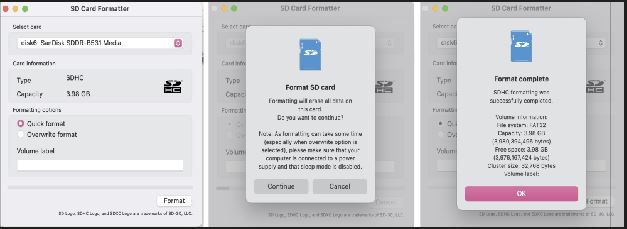
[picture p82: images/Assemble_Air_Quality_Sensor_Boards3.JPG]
SD Card Formatting


---

## 🔧 Sensor Assembly & Testing

**Assembly Strategy:** We'll add and test each sensor individually to ensure proper functionality before final assembly.

### 1. BME 280 Environmental Sensor

**📖 Reference:** [BME280 Datasheet](https://cdn-learn.adafruit.com/downloads/pdf/adafruit-bme280-humidity-barometric-pressure-temperature-sensor-breakout.pdf)

**Function:** Measures temperature, barometric pressure, and humidity.

#### Placement & Wiring

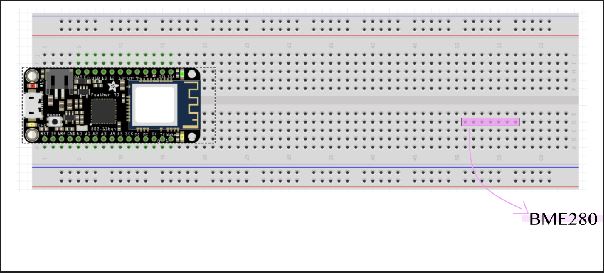
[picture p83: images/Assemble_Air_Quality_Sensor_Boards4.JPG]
BME280 Placement


**Wiring Guidelines:**
- **Power:** Voltage connects to red line (+), ground connects to blue line (-)
- Follow the color coding in the image below for accurate connections

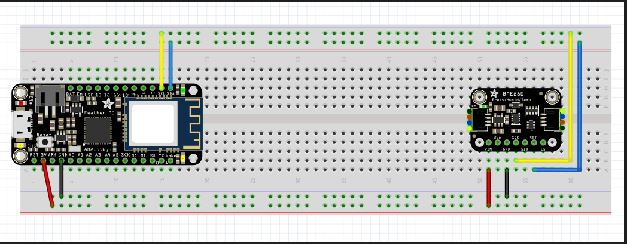
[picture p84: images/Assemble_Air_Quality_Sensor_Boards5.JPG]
BME280 Wiring


**Connection Map:**
- SCK/SCL → Top row of breadboard
- SDI/SDA → Second row of breadboard  
- VIN/3V → Last row of breadboard
- GND → Second to last row of breadboard

#### Testing BME280

1. **Load test code:** Open Examples → BME280 test

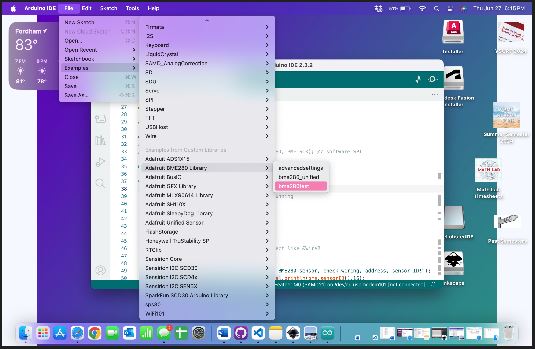
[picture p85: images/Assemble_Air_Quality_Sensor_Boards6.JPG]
BME280 Code


2. **Add debugging code:** After `void setup()` and `Serial.begin();`, add:
   ```arduino
   delay(5000);
   Serial.println(__FILE__);
   ```
   This ensures you can verify successful code execution.

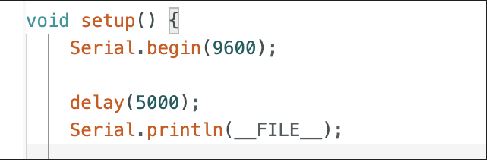
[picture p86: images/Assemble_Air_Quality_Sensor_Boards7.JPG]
BME280 Debug Code


3. **Upload and test:**
   - Connect board with USB data cable
   - Select board and port
   - Verify and upload code
   - Open Serial Monitor to view results
   - **Disconnect USB** before proceeding to next sensor

### 2. SCD41 CO2 Sensor  

**📖 Reference:** [SCD-40 and SCD-41 Datasheet](https://cdn-learn.adafruit.com/downloads/pdf/adafruit-scd-40-and-scd-41.pdf)

**Function:** Photoacoustic CO2 sensor measuring CO2 concentration in PPM (parts per million).

#### Placement & Wiring

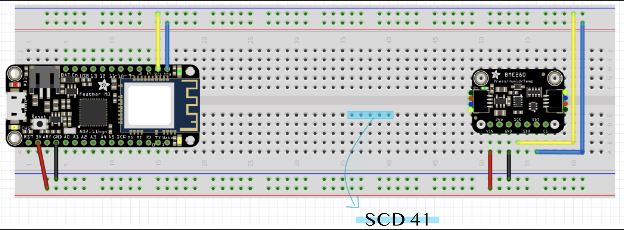
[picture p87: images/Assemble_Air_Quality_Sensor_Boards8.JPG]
SCD41 Placement


**⚠️ Important:** Keep the BME 280 connected when adding SCD41 - it provides necessary pull-up resistors. Alternatively, you can use the OLED display which also has pull-up resistors.

#### Testing SCD41

1. **Load test code:** Examples → Sparkfun SCD4x Arduino Library → Example8_SCD41SingleShot

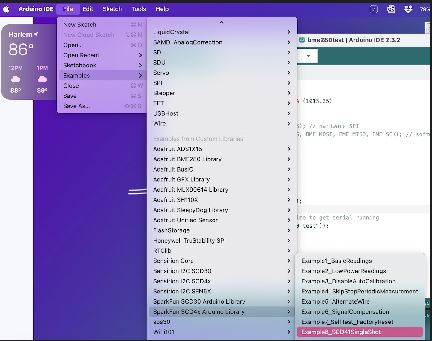
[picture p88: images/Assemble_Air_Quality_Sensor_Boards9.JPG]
SCD41 Code Selection


2. **Modify settings:** 
   - Change line 35 to `false false false`

SCD41 Code Modification

   - Comment out lines 76-92

SCD41 Code Comments

3. **Test:** Follow the same upload and testing procedure as BME 280
4. **Disconnect USB** before proceeding

### 3. SEN55 All-in-One Environmental Sensor

**📖 Reference:** [SEN5x Datasheet](https://sensirion.com/media/documents/6791EFA0/62A1F68F/Sensirion_Datasheet_Environmental_Node_SEN5x.pdf)

**Function:** Comprehensive sensor measuring:
- Particulate matter (PM1.0, PM2.5, PM4.0, PM10)
- Volatile organic compounds (VOCs)
- Humidity and temperature
- Oxidizing gases (NOx)

#### Placement & Wiring

SEN55 Placement

**Note:** Keep BME 280 connected for pull-up resistors (or use OLED display as alternative).

SEN55 Wiring

#### Testing SEN55

1. **Load test code:** Examples → Sensirion I2C SEN5x → exampleusage
2. **Test:** Follow the same upload and testing procedure as previous sensors
3. **Disconnect USB** before final assembly

SEN55 Testing

---

## 🎯 Final Assembly

Once all individual sensors have been tested successfully, assemble all components together on the breadboard as shown:

Final Assembly

**Final Steps:**
1. Carefully arrange all components according to the layout
2. Double-check all connections match the individual sensor wiring
3. Ensure no loose connections
4. Upload your main AQI monitoring code
5. Test the complete system

---

## 📚 Additional Resources

- [Community Sensor Lab GitHub Repository](https://github.com/Community-Sensor-Lab/Air-Quality-Sensor)
- [Arduino IDE Download](https://www.arduino.cc/en/software)
- [Adafruit Learning System](https://learn.adafruit.com/)

---

## ⚠️ Safety & Best Practices

- Always disconnect USB power before modifying wiring
- Double-check connections before powering on
- Handle sensors gently to avoid damage
- Keep workspace organized and well-lit
- Test each component individually before final assembly

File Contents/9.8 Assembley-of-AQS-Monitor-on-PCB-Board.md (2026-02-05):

# Assembly of Air Quality Monitor Components on a PCB Board

## Materials:

- PCB board
- [Feather M0 WiFi (WINC1500)](https://www.adafruit.com/product/3010) Microcontroller and WiFi Radio
- [Featherwing Logger (RTC microSD)](https://www.adafruit.com/product/2922) Real-time Clock and MicroSD Reader
- [Featherwing OLED 128x64](https://www.adafruit.com/product/2900) Display Screen
- [Adafruit SCD41 CO2 Sensor](https://www.adafruit.com/product/5190)
- [BME280 Temp. Press. Rel Humidity Sensor](https://www.adafruit.com/product/2652)
- [Sensirion SEK-SEN5X](https://www.sensirion.com/products/catalog/SEK-SEN5X/) Particulate Matter/VOC/NOX Sensor
- [MiniBoost 5V](https://www.adafruit.com/product/4654)
- Standoff Screws with Hex Nuts and Cap Screw Bolt
- Battery Pack

## Tools:

- [H 1.5 Screwdriver](https://www.adafruit.com/product/3790)

## Assembly STEPS

1. Place the PCB in the same orientation as the Photo.

PCB Board Orientation

---

## Step I. Connect the Feather M0 WiFi (WINC1500)

1. **Locate the Feather M0 WiFi:**
   - Notice that the PCB board's label, "Feather M0 WiFi," is printed on the upper left-hand side.

2. **Align the Feather M0 WiFi:**
   - Before making any connections, carefully align the header pins directly above the female sockets on the PCB. Double-check to ensure that all pins are correctly positioned over the corresponding sockets.

3. **Position and Check Alignment:**
   - Ensure that the pins are directly about the socket and are evenly aligned before pressing them into place. Any misalignment could cause the pins to bend or damage them.

4. **Gently Insert the Pins:**
   - With the pins aligned, gently press the Feather M0 WiFi into the sockets. Apply light pressure, and if necessary, gently wiggle the board slightly to help the pins slide smoothly into the sockets.

PCB Board Orientation

**Note:** The Feather M0 WiFi (WINC1500) is equivalent to a computer's central processing unit (CPU).

---

## Step II. Connect the Featherwing Logger (RTC MicroSD)

1. **Locate the Feather M0 Adalogger:**
   - Notice that the PCB board's label, "Feather M0 Adalogger," is printed on the bottom left-hand side.
   - Follow the same installation techniques and instructions above.

PCB Board Orientation

**Note:** The Featherwing M0 AdaLogger is equivalent to a computer's memory and data storage.

---

## Step III. Connect the BME280 Temp. Pressure Relative Humidity Sensor

1. **Locate the [BME280](https://www.bosch-sensortec.com/products/environmental-sensors/humidity-sensors-bme280/) Temp. Pressure, and Humidity Sensor:**
   - This sensor has seven pins. Locate the label 'BME280' printed on the board.
   - Connect the BME280 sensor by inserting the pins in the 7-pin socket.

PCB Board Orientation
---

## Step IV. Connect the MiniBoost 5V - 3.3 to 5V (Voltage) Converter

1. **Locate the MiniBoost 5V - 3.3 to 5V Voltage Converter:**
   - Connect the MiniBoost 5V directly below the BME280 sensor.
   - Insert the four pins in the sockets labeled: 3V, GND, 5V, and EN.

PCB Board Orientation

---

## Step V. Connect the Adafruit SCD41 CO2 Sensor

1. **Locate the SCD41 CO2 Sensor:**
   - Locate the label 'SCD' printed on the board.
   - Connect the SCD41 CO2 Sensor to the right of the BME280 sensor.
   - Insert the five pins into the sockets labeled SDA, SCL, GND, 3V0, and 3.3V.

PCB Board Orientation
---

## Step VI. Connect the Featherwing OLED 128x64 Display Screen

1. **Locate the OLED Display Screen:**
   - Locate the OLED Display Screen.
   - Connect the OLED Display to the Feather M0 WiFi.
   - Align the pins and press gently until they are completely inserted and no longer visible.

PCB Board Orientation

**Note:** The OLED Display is equivalent to a computer screen.

---

## Step VII. Connect the Sensirion SEK-SEN5X Particulate Matter/VOC/NOX Sensor

1. **Locate the Sensirion SEK-SEN5X Particulate Matter/VOC/NOX Sensor:**
   - The sensor has six color-coded wires connected to pins.
   - On the board to the right of the MiniBoost 5V 3.3 to 5V Voltage Converter, locate the six sockets labeled 5V, GND, SDA, SCL, and GND.
   - Align the pins starting with the labeled red 5V wire, and align it with the 5V socket.
   - Carefully locate the corresponding sockets for each color-coded wire from the sensor.
   - The last wire, colored purple, should be connected to the previous socket labeled GND.
   - Connect the wires to the corresponding sockets, making sure the pins are no longer visible.
   - Align the pins and press gently until they are completely inserted and no longer visible.

PCB Board Orientation

---

## Final Assembly Notes

### Power Connection
- Connect your battery pack to provide power to the entire system
- The MiniBoost 5V converter will regulate power distribution to components requiring different voltages

### Testing
- Once all components are installed, power on the system
- The OLED display should show initialization messages
- Verify all sensors are detected and providing readings

### Troubleshooting
- If components are not detected, check all connections are secure
- Ensure pins are fully inserted into their sockets
- Verify correct alignment of all components

## Next Steps

After successful assembly, you'll need to:
1. Install the appropriate firmware
2. Configure WiFi settings for data transmission
3. Set up data logging and monitoring
4. Calibrate sensors if required

Your air quality monitor is now ready to help track environmental conditions and contribute to community air quality awareness!

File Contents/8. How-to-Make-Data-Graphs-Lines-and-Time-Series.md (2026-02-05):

**Creating Charts with the Spreadsheet**

**Step I.** Use this Template[Walkshop-data](https://docs.google.com/spreadsheets/d/1RFhmyqTI_-M0KqMQCdK-JjGWuWDufaKyo__DD6yt2HA/edit?usp=sharing)

**Step II.** To select all data, follow the instructions below:

* Place the **cursor on Row 3, Column A**.   
  * To **Select** all Data on Google Sheets on a Mac: **Press Ctrl \+ Shift,**   
  * Now press the **↓Down Arrow** while still **pressing the Ctrl \+ Shift** (this will highlight selecting all the data in column A.    
  * To select the data across all Rows and Columns, **press the → Right Arrow**. Now, all of the data across the spreadsheet should be highlighted.

  

  * For Mac, with the cursor on  

**Step III.** To create the graph, Go to **Insert** and select **Chart** from the drop-down menu.


* A chart should pop up on top of your datasheet. 

**Step IV:** Click on the **three dots** at the top right corner of the chart and Select “**Move to own Sheet**.” This allows you to move a chart from its current location, embedded within a sheet, to a separate, dedicated new sheet.



**Chart Editor:** The Chart Editor allows users to create, customize, and modify charts or graphs based on the data within the spreadsheet.

 
**Step VI.** A new sheet tab is created at the bottom of your Google Sheets file.
Click on the **down arrow** and select **rename**   
to give the sheet a new name. 

**Step VII.** Click **Edit Chart** to open the Chart editor, which will appear on the right side of the screen.



**Step VIII: Label X-Axis using the Chart Editor**

* Click “**Add X-axis**” in the Chart editor and select **Google Datatime**.



**Google Datetime** allows you to format and represent date and time data on charts, making it easier to visualize trends over specific periods.

**Step VIII: Remove Series**

* In this section of the **Chart Editor**, you will remove 

Next remove Google Datetime,   
Series Datetime, V, status and any other   
series you may not want to put in this   
particular graph.



Change the chart type under set up into a line chart and it should look like this



**Creating a Timeline Chart**

To make a timeline chart click timeline chart under chart type



Be sure to have the following boxes selected:



Press the cell boxes under Data range and select the data ranges from your data sheet (Sheet1) that you would like to include in the timeline chart.



Your graph should now look like this (depending on the range cells you selected):  
\[In my case I selected all of A and C to H for: CO2, temp, humidity and pressure.\]



**Customize Data Lines**

Under the chart editor you can also customize the chart by changing the fill opacity or the line thickness using the drop down menu.



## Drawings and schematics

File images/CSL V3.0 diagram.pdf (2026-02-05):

# Community Sensor Lab: V3.0

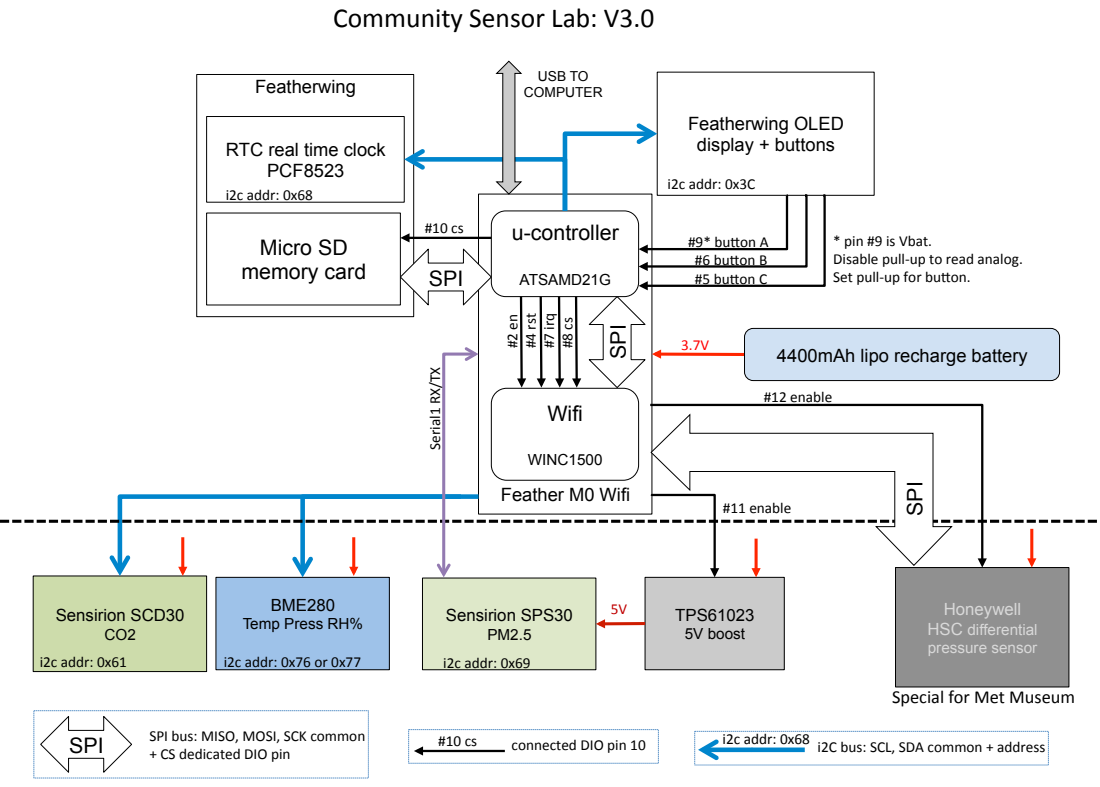
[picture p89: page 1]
Feather M0 Wifi; u-controller; ATSAMD21G; Wifi; WINC1500; SPI; #4 rst; #7 irq #8 cs; Featherwing; Micro SD; memory card; Featherwing OLED display + buttons; i2c addr: 0x3C; Sensirion SCD30 CO2; Sensirion SPS30 PM2.5; i2c addr: 0x61; i2c addr: 0x76 or 0x77; i2c addr: 0x69; Honeywell HSC differential pressure sensor; #11 enable; TPS61023 5V boost; #12 enable; 4400mAh lipo recharge battery; USB TO COMPUTER; Serial1 RX/TX; SPI bus: MISO, MOSI, SCK common; connected DIO pin 10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

RTC real time clock
PCF8523
i2c addr: 0x68

* pin #9 is Vbat.
Disable pull-up to read analog.
Set pull-up for bu<on.

Special for Met Museum SPI

BME280
Temp Press RH%

+ CS dedicated DIO pin

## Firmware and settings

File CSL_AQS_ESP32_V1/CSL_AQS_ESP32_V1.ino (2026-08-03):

/*
   COMMUNITY SENSOR LAB - AIR QUALITY SENSOR

   Adafruit Feather ESP32 V2 + Featherwing Adalogger-SD-RTC + SCD30 OR SCD41 -CO2 + BME280 -TPRH + OLED display + SEN55 -PM2.5 VOC NOX

   The SCD30 has a minimum power consumption of 5mA and cannot be stop-started. It's set to 55s (30s nominal)
   sampling period and the featherM0 sleeps for 2 x 16 =32s, wakes and waits for data available.
   Button A toggles display on/off but must be held down for 16s max and then wait 16s to toggle again.

   Logs: sensor, co2, 3x t, 3x rh, press, battery voltage, pm1, pm 2.5, pm 4.0, pm 10, voc, nox 

   https://github.com/Community-Sensor-Lab/Air-Quality-Sensor

   RICARDO TOLEDO-CROW NGENS, ESI, ASRC, CUNY, May 2025
//Mac Address Testing
*/
#include "CSL_AQS_ESP32_V1.h"

void setup() {

  Serial.begin(115200);
  delay(5000);
  Serial.println(__FILE__);

  initializeSD();     // initializeSD has to come before initializeOLED or it'll crash
  initializeOLED();   // display
  initializeSEN55();  // PM VOC NOX sensor
  initializeSCD41();  // CO2
  //initializeSCD30(25);       // CO2 sensor to 30s more stable (1 min max recommended)
  initializeBME();  // TPRH
  initializeRTC();  // clock
  //delay(8000);

  logfile.println(HEADER);
  logfile.flush();

  Serial.printf("To force provisioning press button A\n");
  Serial.printf("To continue without WiFi press button B\n");
  display.printf("Provisioning: bttn A\n");
  display.printf("No WiFi: bttn B\n");
  display.display();

  provisioningFromEEPROM();  // get EEPROM info

  Serial.printf("10s to decide\n");
  unsigned long ts = millis();

  if (provisionInfo.valid) {  // ENTER IF PROVISION VALID, EXIT IF EITHER A OR B PRESSED OR TIMEOUT. IF EEPROM READ IS INVALID SKIPS
    int i = 10;

    while (millis() - ts < WIFI_TIMEOUT && provisionInfo.valid && provisionInfo.WiFiPresent) {
      Serial.printf("%d ", i--);
      delay(1000);
    }
    Serial.println();
  }

  // If we have a valid provision and wifi, try it out
  if (provisionInfo.valid && provisionInfo.WiFiPresent) {
    connectToWiFi();
  }

  // Go for provisioning. ENTER HERE IF TIMED OUT OR PROVISION NOT VALID OR A PRESSED OR B PRESSED
  while (!provisionInfo.valid && provisionInfo.WiFiPresent) {  // ENTER IF A PRESSED OR PROVISION NOT VALID

    uint32_t mac_reversed = (uint32_t)(ESP.getEfuseMac() >> 24) & 0xFFFFFF;
    uint32_t mac_original = ((mac_reversed & 0xFF) << 16) | ((mac_reversed & 0xFF00)) | ((mac_reversed & 0xFF0000) >> 16);  //Shift addresses to correct positions

    mac_ssid = "csl-" + String(mac_original, HEX);
    // mac_ssid = "csl-" + String((uint32_t)(ESP.getEfuseMac() >> 24) & 0xFFFFFF, HEX);

    Serial.println("going to softAPprovision");
    softAPprovision();  // may change to not valid
    if (provisionInfo.valid && provisionInfo.WiFiPresent) {
      connectToWiFi();
    }
  }

  if (!provisionInfo.WiFiPresent) {
    Serial.println("No WiFi present. Continuing without WiFi.");
    display.printf("No WiFi\n");
    display.display();
  }
  if (WiFi.status() == WL_CONNECTED) {
    syncRTCFromNTP();

    initializeClient();
    Serial.println("*** Adding header to google sheet. ");
    doPost(PRE_PAYLOAD_ADD_HEADER HEADER);
    Serial.println("\n*** Done adding header to google sheet");
    delay(5000);
  }
}

void loop() {

  String bme = readBME();
  String sen55 = readSEN55();
  String scd41 = readSCD41();
  DateTime now = rtc.now();  // fetch the date + time

  String rssi_quality;          //intializes wifi quality variable
  int wifi_rssi = WiFi.RSSI();  //variable for the rssi strength

  if (wifi_rssi > -50) rssi_quality = "Excellent";
  else if (wifi_rssi > -60) rssi_quality = "Good";
  else if (wifi_rssi > -70) rssi_quality = "Fair";
  else rssi_quality = "Poor";

  pinMode(VBATPIN, INPUT);  // read battery voltage
  sensorData.Vbat = float(analogReadMilliVolts(VBATPIN) * 2.0 / 1000.00);
  pinMode(BUTTON_A, INPUT_PULLUP);

  char tstring[128];
  sprintf(tstring, "%02u/%02u/%02u %02u:%02u:%02u, ", now.year(), now.month(), now.day(), now.hour(), now.minute(), now.second());

  String outString = String(tstring) + bme + scd41 + sen55 + String(sensorData.Vbat) + "," + FullmacStr + "," + String(provisionInfo.ssid) + "," + wifi_rssi + "," + rssi_quality;  //adds all the clumns values

  Serial.println(HEADER);
  Serial.println(outString);

  logfile.println(outString);
  logfile.flush();

  display.clearDisplay();
  display.setCursor(0, 0);
  display.printf("Temp: %.2f C\nP: %.2f mBar\nRH: %.2f%%\n", sensorData.Tbme, sensorData.Pbme, sensorData.RHbme);
  display.printf("CO2: %d ppm\nPM2.5: %.2f ug/m^3\nVOCs: %.2f\n", sensorData.CO2, sensorData.mPm2_5, sensorData.VOCs);
  display.printf("Bat: %.2f V\n", sensorData.Vbat);
  display.display();

  if (WiFi.status() == WL_CONNECTED) {
    doPost(PRE_PAYLOAD_APPEND_ROW + outString);
  }
  if (!provisionInfo.valid && provisionInfo.WiFiPresent) {
    softAPprovision();
    connectToWiFi();
  }
  if (!provisionInfo.WiFiPresent) {
    Serial.println("No WiFi");
    display.println("No WiFi");
    display.display();
  }

  delay(60000);  // 1 minute
}

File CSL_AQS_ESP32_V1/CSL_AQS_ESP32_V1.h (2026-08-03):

#ifndef CSL_AQI_ESP32_V1_H
#define CSL_AQI_ESP32_V1_H

#include <SPI.h>
#include <SD.h>
#include <FS.h>
#include <Wire.h>
#include <WiFi.h>
#include <WebServer.h>
#include <RTClib.h>
#include <time.h>
// #include <Adafruit_GFX.h>
#include <Adafruit_SH110X.h>  // OLED library

#define VBATPIN A13  // this is also D9 button A disable pullup to read analog
#define BUTTON_A 15  // for the adafruit Feather ESP32 v2 (ABC, 15 32 14) Oled button also A7 enable pullup to read button
#define BUTTON_B 32  // for the adafruit Feather ESP32 v2 (ABC, 15 32 14) Oled button also A7 enable pullup to read button
#define WIFI_TIMEOUT 10000 // how long to wait for connection in ms
//#define SD_CS 10    // Chip select for SD card default for Adalogger

/* STRUCT TO STORE ALL SENSOR DATA */
typedef struct {
  DateTime now; 
  float Tbme;  // BME280 temperature C
  float Pbme;  // BME280 pressure mBar
  float RHbme; // BME280 relative humidity %

  uint16_t CO2; // SCD41 C02 in ppm
  float Tco2;   // SCD41 temperature C
  float RHco2;  // SCD41 relative humidity %
  
  float mPm1_0; // SEN55 pm1.0 in ug/m^3
  float mPm2_5; // SEN55 pm2.5 in ug/m^3
  float mPm4_0; // SEN55 pm4.0 in ug/m^3
  float mPm10;  // SEN55 pm10  in ug/m^3

  float cPm0_5; // SEN55 pm0.5 in #/cm^3
  float cPm1_0; // SEN55 pm1.0 in #/cm^3
  float cPm2_5; // SEN55 pm2.5 in #/cm^3
  float cPm4_0; // SEN55 pm4.0 in #/cm^3
  float cPm10;  // SEN55 pm10  in #/cm^3
  float tpSize; // SEN55 typical particle Size

  float RHsen; // SEN55 relative humidity %
  float Tsen;  // SEN55 temperature C
  float VOCs;  // SEN55 VOCs index [1..500] 
  float NOx;   // SEN55 NOx index [1..500]

  float Vbat;
} data;

data sensorData; // instantiate a sensor data structure

// global web server
static WebServer server(80);
static String mac_ssid;
String FullmacStr = "";

// the title of the columns
#define HEADER "DateTime, Tbme, Pbme, RHbme, CO2, Tco2, RHco2, mPm1.0, mPm2.5, mPm4.0, mPm10, cPm0.5, cPm1.0, cPm2.5, cPm4.0, cPm10, cPm tSize, RHsen, Tsen, VOCs, NOx, Vbat, ID (Mac Address), WiFi, WiFi rssi (dBm), WiFi Quality" 

// large Oled display
Adafruit_SH1107 display = Adafruit_SH1107(64, 128, &Wire);

// Clock and SD card
RTC_PCF8523 rtc;                                                 // Real Time Clock for RevB Adafruit logger shield
File logfile;                                                    // the logging file

// wifi and google sheets provisioning 
// typedef struct {
//   boolean valid;
//   char ssid[64];
//   char passcode[64];
//   char gsid[128];
//   boolean WiFiPresent;
// } Secrets;
// Secrets provisionInfo;

struct Secrets {
  bool  valid;
  char  ssid[64];
  char  passcode[64];
  char  gsid[128];
  bool  WiFiPresent;
};

// A versioned, checksummed record stored in EEPROM.
struct SecretsRecord {
  uint32_t magic;      // constant marker
  uint16_t version;    // increment when struct layout changes
  uint16_t length;     // sizeof(Secrets) at time of write
  uint32_t crc32;      // CRC of payload only
  Secrets  payload;
};

// constants
static constexpr uint32_t SECRETS_MAGIC   = 0x53454352; // 'SECR'
static constexpr uint16_t SECRETS_VERSION = 1;
static constexpr int      EEPROM_ADDR     = 0;

Secrets provisionInfo;

#define PRE_PAYLOAD_APPEND_ROW "{\"command\":\"appendRow\",\"sheet_name\":\"Sheet1\",\"values\":\""
#define PRE_PAYLOAD_ADD_HEADER "{\"command\":\"addHeader\",\"sheet_name\":\"Sheet1\",\"values\":\""

/* OLD CODE FOR WEBPAGE
static const char provisioningPage[] = R"===(
<!DOCTYPE HTML><html><head>
  <title>Community Sensor Lab provisioning page</title>
  <meta name="viewport" content="width=device-width, initial-scale=1">
  </head><body>
  <form action="/get">
    ssid: <input type="text" name="SSID"><br>
    <!-- <input type="submit" value="Submit">
  </form><br>
  <form action="/get"> -->
    passcode: <input type="password" name="passcode"><br>
    <!-- <input type="submit" value="Submit">
   </form><br>
 <form action="/get"> -->
    gsid: <input type="text" name="GSID"><br>
    <input type="submit" value="Submit">
  </form>
</body></html>
)===";
*/
void syncRTCFromNTP();
#endif

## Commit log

2025-07-18 added remote sample period update
2025-07-18 fixed small syntax errors
    [CSL_AQS_ESP32_V1.ino]
2025-07-31 fixed mac address problem
    we were gettting the same mac address on all systems
    [CSL_AQS_ESP32_V1.ino, softAPprovisioning.ino]
2025-07-31 fixed some formatting text
    [SD_RTC.ino, softAPprovisioning.ino]
2026-02-05 added all context files #1
    [0603-NO.ipt, 0805-NO.ipt, 2652 BMP280 STEMMA QT.ipt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]
2026-02-11 Fix image path for Custom PCB CSL in Parts List
2026-03-11 Fixed the provisioning problem
    Now it lets you skip to provisioning or no-wifi seamlessly. Also will try valid provisioning info and go to provisioning if not good. Also fixes the problem that sometimes the provisioning page did not show any SSIDs
    [CSL_AQS_ESP32_V1.ino, eeprom.ino, softAPprovisioning.ino]
2026-03-11 fixed the unique mac_ssid
    we were using the lowest 24 bits that are common to all espresiff
    [CSL_AQS_ESP32_V1.ino]
2026-05-01 Modified new EEPROM State Procedure
    Solved an issue linked to new ESP32's with empty Wi-Fi memory to skip provisioning
    [eeprom.ino]

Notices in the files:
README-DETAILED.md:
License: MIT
